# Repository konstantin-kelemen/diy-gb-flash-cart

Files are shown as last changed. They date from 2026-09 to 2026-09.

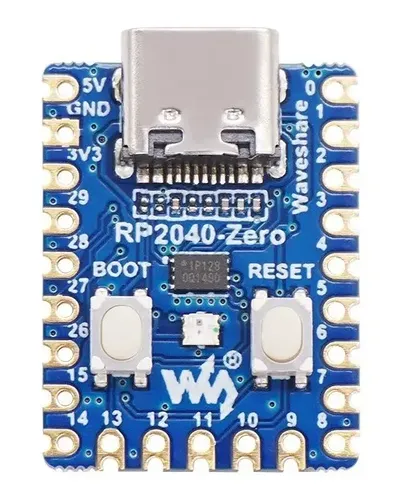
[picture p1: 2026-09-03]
references/datasheets/RP2040/RP2040-Zero.png

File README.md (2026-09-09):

# FPGA-картридж с Flash-памятью для Game Boy

Экспериментальный USB-программируемый картридж для оригинального Game Boy:
MachXO2-1200HC, NOR Flash MX29LV320E (4 МБ), F-RAM FM28V100 (128 КБ),
RP2040-Zero и преобразователи уровней SN74LVC8T245.

## С чего начать

- [Состояние проекта](docs/STATUS.md) — что реализовано и что проверено.
- [План работ](docs/ROADMAP.md) — следующие этапы и критерии готовности.
- [Документация](docs/README.md) — архитектура, испытания и приоритет источников.
- [Первый обмен USB/SPI](docs/SPI_BRINGUP.md) — подключение стенда и протокол.
- [Запись .gb во Flash](docs/PROGRAMMER.md) — чтение, запись и сравнение ROM.

## Структура репозитория

| Каталог | Содержимое |
|---|---|
| [docs/](docs/README.md) | Проектная документация и журнал испытаний |
| [hardware/](hardware/README.md) | Схемы, PCB и локальные библиотеки KiCad |
| [fpga/](fpga/README.md) | RTL, ограничения, тесты и проект Diamond |
| [firmware/](firmware/README.md) | Прошивки RP2040: SPI-тест и программатор |
| [host/](host/README.md) | Утилита записи и проверки Flash |
| [references/](references/README.md) | Техническая документация и сторонние материалы |
| [releases/](releases/README.md) | Сохранённые сборки и производственные файлы |

Электрические соединения определяет [схема картриджа](hardware/cartridge/cartridge.kicad_sch);
правила сверки приведены в [документации](docs/README.md#приоритет-источников).
Перед работой с памятью см. [режимы и требования безопасности](docs/ARCHITECTURE.md#режимы-работы).

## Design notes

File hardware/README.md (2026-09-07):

# Аппаратная часть

## Проекты

- `breakout/` — разведённая отладочная плата с производственным архивом.
- `cartridge/` — основная схема картриджа и PCB. Состояние разводки — в
  [STATUS.md](../docs/STATUS.md).

## Открытие в KiCad

Открывайте `cartridge/cartridge.kicad_pro` или `breakout/breakout.kicad_pro`.
Локальные библиотеки и 3D-модели картриджа хранятся рядом с проектом;
`fp-lib-table` использует пути относительно `${KIPRJMOD}`.
Для стандартных компонентов также нужны штатные библиотеки KiCad.

В `cartridge/sym-lib-table` пути пяти библиотек пока указывают на каталоги,
а не на конкретные `.kicad_sym`. Перед обновлением символов из библиотек
нужно исправить эти ссылки. Файлы находятся в соответствующих подкаталогах
`cartridge/libraries/`; у RP2040-Zero это `Andrews-symbols.kicad_sym`,
у остальных — файлы с датой в имени. Наличие встроенных символов в схеме
не подтверждает правильность настройки внешних библиотек.

Перед выпуском аппаратной ревизии необходимо выполнить ERC/DRC и сверить LPF с
назначением выводов символа FPGA в схеме.

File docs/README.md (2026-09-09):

# Документация

## Приоритет источников

Единственный нормативный источник электрических соединений —
`hardware/cartridge/cartridge.kicad_sch`.

При расхождении артефакты проверяются в следующем порядке:

1. схема картриджа — соединения и номиналы установленных компонентов;
2. PCB картриджа — размещение и трассировка;
3. ограничения FPGA и константы прошивки — должны соответствовать схеме;
4. сгенерированные перечни компонентов и отчёты по назначениям выводов;
5. пояснительная документация.

Таблицы подключений хранятся только в KiCad; в документации используются ссылки.

## Состав документации

- [STATUS.md](STATUS.md) — проверенные, реализованные и запланированные части.
- [ARCHITECTURE.md](ARCHITECTURE.md) — границы подсистем и требования безопасности.
- [ROADMAP.md](ROADMAP.md) — порядок первичной проверки и критерии готовности.
- [TEST_PLAN.md](TEST_PLAN.md) — обязательные проверки и сохраняемые результаты.
- [SPI_BRINGUP.md](SPI_BRINGUP.md) — подключение RP2040-Zero и протокол первого обмена.
- [PROGRAMMER.md](PROGRAMMER.md) — полный дамп, запись `.gb` и повторное чтение на Mac.
- [PROGRAMMER_PROTOCOL.md](PROGRAMMER_PROTOCOL.md) — блочный USB/SPI-протокол 3.0 и временные параметры.
- [BOM.md](BOM.md) — заметки по комплектации; не источник электрической истины.

`archive/` содержит устаревшие снимки, оставленные только для истории. Они не
должны использоваться при проектировании или закупке.

## Как поддерживать документацию

- Текущий статус хранится в `STATUS.md`, хронология испытаний — в `TEST_PLAN.md`.
- `ROADMAP.md` содержит этапы и критерии; `ARCHITECTURE.md` — общие требования.
- Подключение стенда и SPI 1.0 описаны в `SPI_BRINGUP.md`, протокол программатора 3.0 — в `PROGRAMMER_PROTOCOL.md`.
- README конфигурации содержит сборку, запуск и специфическую диагностику.
- Манифест выпуска фиксирует его исходники, инструменты, отчёты и контрольные суммы.

В остальных местах используйте ссылки вместо копирования таблиц, результатов
и протокола. Исторические манифесты и снимки исходников не актуализируются
вместе с текущим кодом.

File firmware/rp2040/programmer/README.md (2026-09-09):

# RP2040 programmer

Прошивка Waveshare RP2040-Zero для [программатора Flash](../../../docs/PROGRAMMER.md).
Бинарный USB CDC, протокол 3.0 с CRC; SPI0 Mode 0, 4 МГц. UART отключён.
Подключение — по [схеме KiCad](../../../hardware/cartridge/cartridge.kicad_sch).

## Сборка на macOS при изменении прошивки

Требуются Pico SDK с инициализированным TinyUSB, ARM GCC и CMake.
`PICO_SDK_PATH` должен указывать на каталог SDK. Из корня проекта:

```sh
cmake -S firmware/rp2040/programmer -B firmware/rp2040/programmer/build-v3 -DPICO_BOARD=waveshare_rp2040_zero
cmake --build firmware/rp2040/programmer/build-v3 -j4
```

Выход: `firmware/rp2040/programmer/build-v3/gb_cart_programmer.uf2`.
Для стендового опыта с готовым UF2 использовать общую инструкцию выше.

Проверка кода моста с моделью SPI на Mac:

```sh
python3 -m unittest discover -s firmware/rp2040/programmer/tests -v
```

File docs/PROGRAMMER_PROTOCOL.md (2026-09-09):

# Программатор: блочный протокол 3.0

[Порядок работы на Mac](PROGRAMMER.md). Версия 3 несовместима с v2;
UF2 и FPGA обновляются вместе. Размер блока — 1..1024 байта. Память адресуется
байтами, диапазон `000000..3FFFFF`. Все числа ниже, кроме длин, — hex.

## SPI

Mode 0, MSB first, 4 МГц, CS# остаётся низким весь кадр.
Интервалы до первого фронта, после последнего спада и между кадрами — ≥2 мкс.
После запуска RP2040 выдерживается 400 мс. FPGA не выдаёт стартовых команд Flash.

Запрос операции:

```text
command sequence address_hi address_mid address_lo length_hi length_lo key
[payload: length bytes, только WRITE_BLOCK]
crc_hi crc_lo
```

CRC-16/CCITT-FALSE: polynomial 1021, init FFFF, без отражения/xorout.
CRC охватывает заголовок и payload. Запрос исполняется только после снятия CS,
если длина точна, CRC верен, FPGA свободна и sequence отличается от предыдущего.
Sequence увеличивается modulo 256; после подключения сначала читается текущий.
Кадры, начатые во время busy, игнорируются целиком. Неполные и лишние кадры
не исполняются. При ошибке CRC или повторе sequence снимается ARM.

| Command | Назначение |
|---|---|
| 30 | READ_BLOCK: length=1..1024, без payload; обычное чтение разрешено без ARM |
| 31 | WRITE_BLOCK: length=1..1024, payload той же длины; требуется ARM |
| 12 | Стереть сектор по address; length=0, требуется ARM |
| 13 | Прочитать ID и вернуть Flash в read-array; length=0, требуется ARM |
| 14 | Reset/read-array F0; length=0, требуется ARM |
| 20 | ARM: address=0, length=0, key=A5 |
| 21 | LOCK: address=0, length=0, key=0 |

В остальных запросах key=0. WRITE_BLOCK буферизуется целиком до проверки CRC.
FPGA программирует байты последовательно, с Q7/Q5 polling, тайм-аутом и
проверкой прочитанного байта. FF пропускаются; утилита предварительно проверяет
полное стирание затронутых секторов. Аппаратного многобайтового программирования
самого чипа этот протокол не предполагает. На первой ошибке блок останавливается,
ARM снимается, префикс уже записанных байтов сохраняется.

### Запросы ответов

Первый принятый байт, одновременно с opcode, отбрасывается RP2040.
После opcode передаются нулевые dummy bytes:

- `01` + 8 dummy → `47 42 46 43 03 00 00 04`: GBFC, версия 3.0,
  максимальный блок 0400, little-endian.
- `02` + 10 dummy → снимок статуса с CRC:

  ```text
  50 sequence status command result_lo result_hi completed_lo completed_hi crc_hi crc_lo
  ```

- `03` + `length+2` dummy → данные последнего успешного READ_BLOCK и CRC данных.
  Допускается только после готового статуса, совпадения sequence, opcode и длины.
  Следующая операция заменяет предыдущий результат; одновременно выполняется один запрос.

Статусы: 00 success, 01 busy, 02 opcode, 03 timeout, 04 Q5 failure,
05 readback mismatch, 06 controller fault, 07 CRC, 08 address/length,
09 locked, 0A duplicate sequence. `completed` — число успешно обработанных
байтов блока до ошибки; адрес ошибки равен `address + completed`.
У ID `result_lo` — производитель C2, `result_hi` — устройство A7/A8.
LOCK не прерывает уже принятую операцию.

## Бинарный USB CDC

Кадр Mac → RP2040:

```text
47 42 33 51  length_hi length_lo  payload  crc_hi crc_lo
 G  B  3  Q
```

Ответ имеет magic `GB3R`. CRC охватывает два байта длины и payload.
USB длина — big-endian, без magic, длины и CRC. Максимальный payload запроса —
1034 байта, ответа — 1036. Байты передаются без hex-кодирования и преобразования
переводов строк; значения 00/0A/0D допустимы внутри данных.

Payload запроса: одиночный `01` (версия), `02` (статус) либо целый SPI-запрос
операции со своим CRC. Мост проверяет запрос, отправляет его один раз, опрашивает
статус и проверяет sequence/opcode/CRC. Ответ операции — 10 байт статуса;
для успешного READ_BLOCK добавляются `length` байт данных и их SPI CRC.
Все три уровня CRC проверяются утилитой Mac.

Локальная ошибка моста — payload из одного байта: E1 SPI CRC, E2 кадр/CRC/длина,
E3 busy/sequence/count, E4 timeout. Время приёма USB-кадра — до 2 с,
ожидание операции FPGA — до 7 с, чтение ответа на Mac — до 10 с.
После повреждения USB-кадра вход отбрасывается до 100 мс тишины; внутри
оставшегося payload новые magic не ищутся. При подключении Mac выдерживает 2,2 с.
Автоматические повторы отсутствуют, особенно после потенциально принятой записи.
Ошибка требует остановки и выяснения состояния стенда.

## Частота и Flash

OSCH в `programmer` — 53,20 МГц. В LPF задано 64 МГц, но Map отклоняет
это значение для OSCH и применяет 53,20 МГц. Повторный TRACE пройден
на номинальной частоте; [подробности](TEST_PLAN.md#журнал-результатов).
SPI синхронизируется двумя регистрами. RTL-тест пройден при такте FPGA
около 42,55, 53,19 и 64 МГц с SPI 4 МГц. После Map требуется подтвердить
размещение буферов в EBR, использование ресурсов, пути SPI и внешней шины.
RTL-симуляция не подтверждает задержки после размещения и качество проводного монтажа.

Общий `mx29_bus` параметризован: в programmer один шаг чтения — 4 такта,
записи — 32. При 64 МГц от OE#/CE# до выборки проходит 187,5 нс;
WE# удерживается низким 500 нс. Значения по умолчанию сохранены для
`flash_bringup` на 2,08 МГц. Таймеры programmer пересчитаны: старт 16 млн тактов,
program timeout 128 тыс., erase timeout 192 млн. При 53,20 МГц это примерно
301 мс, 2,4 мс и 3,6 с соответственно.

Алгоритм и параметры: [Macronix MX29LV320E v1.3](https://www.macronix.com/Lists/Datasheet/Attachments/8542/MX29LV320E%20T-B,%203V,%2032Mb,%20v1.3.pdf),
таблицы AC и Q7/Q5 polling на рис. 20;
[настройки OSCH MachXO2](https://www.latticesemi.com/-/media/LatticeSemi/Documents/ApplicationNotes/MO/FPGA-TN-02157-3-0-MachXO2-sysCLOCK-PLL-Design-and-User-Guide.ashx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).

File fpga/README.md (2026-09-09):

# Исходники FPGA

## Конфигурации

| Каталог target | Реализация Diamond | Ограничения / инструкция |
|---|---|---|
| `targets/internal_rom/` | `v1_0` | `constraints/internal_rom.lpf`; сборка ниже |
| `targets/flash_bringup/` | `flash_bringup` (активна по умолчанию) | Общий `internal_rom.lpf`; [инструкция](targets/flash_bringup/README.md) |
| `targets/spi_bringup/` | `spi_bringup` | `constraints/spi_bringup.lpf`; [сборка и симуляция](targets/spi_bringup/README.md) |
| `targets/game_rom/` | `game_rom` | `constraints/game_rom.lpf`; [запуск ROM из Flash](targets/game_rom/README.md) |
| `targets/game_mbc5/` | `game_mbc5` | `constraints/game_mbc5.lpf`; [LSDj и F-RAM](targets/game_mbc5/README.md) |
| `targets/programmer/` | `programmer` | `constraints/programmer.lpf`; [запись Flash](targets/programmer/README.md) |

Добавлена GAME-конфигурация MBC5 для LSDj 1 МиБ / RAM 128 КиБ.
RTL и адаптация PROGRAMMER к F-RAM проверены в симуляции; новые JEDEC
ещё не собраны. Старые выпуски PROGRAMMER с диагностикой на 82–83
несовместимы с подключённой F-RAM. Назначения — в
[схеме KiCad](../hardware/cartridge/cartridge.kicad_sch).

Каждая конфигурация содержит собственный `top` и собирается независимо.
Общие модули — в `rtl/`, тесты — в `tests/`, проект — в `diamond/`.

`examples/hello_world.v` — минимальный пример выхода FPGA,
`examples/fram_test.v` — ранний автономный тест F-RAM. Они не подключены
к проекту Diamond. Перед использованием нужны отдельная конфигурация,
проверенный LPF и испытания.

## Работа в Lattice Diamond

Открывать нужно проект `diamond/RomEmu.ldf`, сохраняя рядом всю структуру
каталога `fpga/`: пути к исходникам и ограничениям в проекте относительные.
Копировать один каталог `diamond/` в другое место не следует.

Для обычной сборки `internal_rom`:

1. Выберите в Diamond `File -> Open -> Project` и откройте
   `diamond/RomEmu.ldf`.
2. Убедитесь, что активна реализация `v1_0`. В ней должны быть подключены
   `targets/internal_rom/top.v` и `constraints/internal_rom.lpf`, а модулем
   верхнего уровня должен быть `top`.
3. В окне `Process` последовательно запустите `Synthesize Design`,
   `Map Design`, `Place & Route Design` и `Export Files -> JEDEC File`.
4. Полученный файл находится по пути
   `diamond/v1_0/RomEmu_v1_0.jed`.

Каталог `diamond/v1_0/` содержит только результаты сборки. Он исключён из Git,
может быть удалён и будет создан Diamond заново. Исходный Verilog нужно
редактировать в `targets/` и `rtl/`, ограничения — в `constraints/`, а не в
сгенерированных копиях внутри каталога реализации.

Если Diamond сообщает об отсутствующих исходниках, удалите устаревшие ссылки
из реализации и добавьте нужные файлы через `Add -> Existing File`. Параметр
`Copy source to implementation directory` при этом должен быть отключён, чтобы
в проекте не появлялись отдельные копии исходников.

### Добавление другой конфигурации

Для новой конфигурации следует создавать отдельную реализацию Diamond, не
заменяя файлы в `v1_0`. Реализацию можно добавить через
`Add -> New Implementation`, после чего подключить её `top.v`, общие модули из
`rtl/` и отдельный LPF из `constraints/`. Одновременно активна только одна
реализация; перед сборкой нужно выбрать её через `Set as Active Implementation`
и установить модуль `top` верхним уровнем.

Особенности общего LPF и предупреждения `flash_bringup` описаны в
[README конфигурации](targets/flash_bringup/README.md).

После сохранения проекта через интерфейс Diamond следует проверить, какие
файлы проекта были изменены:

```sh
git diff -- fpga/diamond/RomEmu.ldf fpga/diamond/RomEmu1.sty
git status --short
```

## Проверка назначений выводов

Перед программированием реального устройства нужно выполнить
[процедуру сверки LPF](../docs/TEST_PLAN.md#сверка-lpf). Расхождения нельзя
скрывать изменением текстовой документации.

Состояние аппаратных проверок — в [STATUS.md](../docs/STATUS.md),
сохранённые сборки — в [releases/](../releases/README.md).

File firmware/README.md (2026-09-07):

# Прошивка RP2040

Конфигурация [rp2040/spi_bringup](rp2040/spi_bringup/README.md):
USB CDC-консоль и SPI0 для запроса версии FPGA и повторных тестов.
Команд памяти в ней нет.

[rp2040/programmer](rp2040/programmer/README.md) — USB/SPI-мост для записи Flash,
работающий с FPGA `programmer` и `host/gbflash.py`.
[Полная инструкция](../docs/PROGRAMMER.md),
[аппаратный результат](../docs/TEST_PLAN.md#журнал-результатов).

Инструкции сборки находятся в README соответствующей конфигурации.
[Подключение стенда](../docs/SPI_BRINGUP.md) общее для обеих конфигураций;
[протокол программатора](../docs/PROGRAMMER_PROTOCOL.md) описан отдельно.

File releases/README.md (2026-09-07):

# Выпуски

В этом каталоге хранятся сохранённые выходные файлы. Уровень проверки каждого
артефакта указан отдельно: здесь есть успешные и неуспешные FPGA-сборки,
а также UF2 без подтверждённого аппаратного испытания.

Каждый новый выпуск должен содержать манифест с именем конфигурации, исходным
коммитом, версией инструментов, контрольными суммами и результатами проверки
(для FPGA — также сводкой DRC и временного анализа). Если сборка сделана
с незакоммиченными изменениями, нужен точный снимок исходников с суммами:
одного базового коммита недостаточно.
Артефакт сборки нельзя считать проверенным на аппаратуре, если такая проверка
явно не зафиксирована в манифесте.

## FPGA

- [spi_bringup](fpga/spi_bringup/MANIFEST.md) — оригинальный рабочий SPI-тест,
  протокол 1.0, аппаратный PASS 1000/1000.
- [programmer-v3](fpga/programmer-v3/MANIFEST.md) — рабочий блочный программатор,
  аппаратный PASS полного цикла Flash; сохранены JEDEC и успешный TRACE.
- [flash-bringup-pass](fpga/flash-bringup-pass/MANIFEST.md) — рабочая сборка
  Flash-теста со стартовым сбросом; PASS после прошивки и выключения/включения питания.
- [flash-bringup-fail](fpga/flash-bringup-fail/MANIFEST.md) — прежняя сборка с FAIL.
- [internal-rom-baseline](fpga/internal-rom-baseline/MANIFEST.md) — базовая
  проверенная конфигурация с внутренним ПЗУ.

## RP2040

[spi_bringup/gb_cart_rp2040.uf2](rp2040/spi_bringup/gb_cart_rp2040.uf2) —
последняя локальная сборка для USB/SPI. [Манифест](rp2040/spi_bringup/MANIFEST.md)
содержит метаданные, SHA-256 и аппаратный результат: 1000/1000, PASS,
включая успешный повтор после выключения/включения питания. [Сборка из исходников](../firmware/rp2040/spi_bringup/README.md#сборка).

[programmer-v3](rp2040/programmer-v3/MANIFEST.md) — блочный программатор,
актуальный UF2 для протокола 3.0. Полный цикл Flash проверен с
[FPGA programmer-v3](fpga/programmer-v3/MANIFEST.md) — PASS.
Исторический снимок FPGA в выпуске UF2 предшествует исправлению timing. [programmer v2](rp2040/programmer/MANIFEST.md) —
прежний несовместимый выпуск.

## Отладочная плата

[breakout/v1.0.zip](breakout/v1.0.zip) — производственный архив отладочной платы;
отдельный манифест выпуска ещё не подготовлен.

## Проверка контрольных сумм

Из корня репозитория:

```sh
cd releases/fpga/flash-bringup-pass
shasum -a 256 -c SHA256SUMS.txt
```

В `.gitattributes` для всего `releases/`, включая снимки исходников и
манифесты, отключено преобразование переводов строк. Файлы сохраняются
побайтово независимо от `core.autocrlf`.

В семи текстовых файлах `flash-bringup-pass` и отчёте `.pad` выпуска
`flash-bringup-fail` восстановлены исходные CRLF, подтверждённые опубликованными
SHA-256. Список сумм и манифесты сохранены без изменений. Проверены все суммы
из `SHA256SUMS.txt` и таблиц двух остальных FPGA-манифестов; расхождений нет.

Манифесты описывают состояние на момент выпуска. Их упоминания рабочего дерева
и следующих шагов относятся к тому испытанию; актуальный план — в
[документации проекта](../docs/README.md).

При подготовке нового выпуска сначала завершите его содержимое и манифест,
затем вычислите контрольные суммы. После добавления файлов в Git проверьте
суммы повторно на чистом checkout.

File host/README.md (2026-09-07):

# Программа для компьютера

`gbflash.py` — утилита macOS для работы с Flash через USB CDC прошивки RP2040
`programmer`. [Подготовка и полный цикл чтения, записи и сравнения](../docs/PROGRAMMER.md).

Проверка утилиты из корня проекта:

```sh
python3 -m unittest discover -s host/tests -v
```

Дополнительные команды доступны через `python3 host/gbflash.py --help`.

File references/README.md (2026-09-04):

# Справочные материалы

- `datasheets/` содержит локальные копии технической документации на выбранные
  компоненты.
- `third-party/` содержит сторонние аппаратные проекты и модели корпусов.

Сторонние файлы не являются частью собственного проекта. Для каждого
импортированного материала следует сохранять исходную лицензию и сведения о
происхождении рядом с файлами.

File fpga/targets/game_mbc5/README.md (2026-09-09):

# LSDj: MBC5 и F-RAM

Отдельная GAME-конфигурация для `roms/lsdj9_4_2.gb`: 1 МиБ ROM,
заголовок `1B 05 04`, 128 КиБ RAM. RTL проверен; сборка Diamond,
post-route timing и запуск на Game Boy ещё не выполнены.
Соединения хранятся в [схеме KiCad](../../../hardware/cartridge/cartridge.kicad_sch).

## Поведение

Регистры соответствуют [MBC5 / Pan Docs](https://raw.githubusercontent.com/gbdev/pandocs/master/src/MBC5.md):
фиксированный банк 0 в `0000–3FFF`, переключаемый банк в `4000–7FFF`,
RAM в `A000–BFFF` при активном CS#. Банк ROM 0 допустим в обоих окнах.
Запись в `2000–2FFF` задаёт младшие 8 бит, в `3000–3FFF` — девятый бит.
Физически используются только младшие 6 бит: образ 1 МиБ зеркалируется.

Запись в `0000–1FFF` разрешает RAM, если младшая тетрада равна A;
остальные значения запрещают RAM. В `4000–5FFF` выбирается один из
16 банков RAM младшей тетрадой данных. Rumble отсутствует.
После конфигурации и при RESET# LOW: банк ROM 1, RAM 0, RAM запрещена.
Регистры принимают данные на положительном фронте WR# при RD# HIGH.
Неиспользуемые записи игнорируются. Чтение запрещённой RAM возвращает FF.

Flash WE# постоянно HIGH. Памяти выбираются взаимоисключающе, FPGA
выдаёт данные на общую шину только при записи RAM. Вход преобразователя
Game Boy остаётся включённым между транзакциями и после WR#, чтобы не
обрезать удержание данных при записи регистров. При чтении направление
меняется к Game Boy; при сбросе преобразователь отключён.

F-RAM CE# активен только на время обращения RD#/WR# и отпускается между
ними. Это обеспечивает отдельный цикл precharge, если длительность паузы
соответствует [FM28V100, стр. 8–11](https://www.infineon.com/assets/row/public/documents/10/49/infineon-fm28v100-1-mbit-128k-x-8-f-ram-memory-datasheet-en.pdf).
Для 3,3 В требуются CE# LOW не менее 60 нс, precharge не менее 30 нс,
WE# LOW не менее 18 нс, setup данных записи не менее 15 нс.
RTL не растягивает внешние импульсы и не содержит внутреннего генератора.

## Проверка на Mac

Из корня проекта с установленным Icarus Verilog:

```sh
iverilog -g2012 -Wall -s game_mbc5_tb -o /tmp/game-mbc5.vvp fpga/targets/game_mbc5/top.v fpga/tests/game_mbc5_tb.sv
vvp /tmp/game-mbc5.vvp
python3 -m unittest discover -s host/tests -v
```

Покрытие и результаты — в [журнале испытаний](../../../docs/TEST_PLAN.md#журнал-результатов).
Модель: Flash 70 нс, F-RAM 90 нс, преобразователь 5 нс; чтение проверяется
через 160 нс. Проверяются длительности CE#/WE#, precharge и setup данных.
Host-тест выполняет два полных чтения 4 МиБ и запись LSDj между ними
для Top/Bottom Boot; при отсутствии локального ROM используется синтетический
образ того же размера. Это симуляция, аппаратные дампы не создаются.

## Сборка в Windows

Открыть `fpga/diamond/RomEmu.ldf`, выбрать **game_mbc5**, верхний модуль `top`.
Выполнить синтез, Map, Place & Route, TRACE и экспорт JEDEC.
Ожидаемый путь — `fpga/diamond/game_mbc5/RomEmu_game_mbc5.jed`.
Для записи Flash отдельно собрать обновлённый **programmer**;
RP2040 `programmer-v3` и текущая утилита Mac совместимы без изменения протокола.
Старый JEDEC `releases/fpga/programmer-v3/` не подходит для подключённой F-RAM.

LPF фиксирует выводы и электрические стандарты. Временные требования пока
не закрыты; отсутствие ошибок TRACE без заданных внешних требований
не является PASS. Проверить `.pad` по [процедуре](../../../docs/TEST_PLAN.md#сверка-lpf).
Проверить задержки адреса к памяти, RD#/WR#/CS# к CE#/OE#/WE#, памяти
к Game Boy, Game Boy к F-RAM и setup/hold регистров относительно WR#.
Учесть преобразователи, разводку, выключение выходов памяти и смену DIR,
hold данных относительно конца WE#/CE#, reset recovery/removal и старт F-RAM.
Поддержка ускоренного режима GBC аппаратно не подтверждена.

[Состав выпуска](../../../releases/README.md),
[порядок аппаратных испытаний](../../../docs/ROADMAP.md).

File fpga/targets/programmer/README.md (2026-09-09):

# FPGA programmer

Отдельная конфигурация PROGRAMMER без интерфейса Game Boy.
`top.v` объединяет `programmer_block.v`, `mx29_programmer.v` и `mx29_bus.v`.
Входной и выходной блоки по 1 КиБ хранятся в синхронной памяти для вывода в EBR.
LPF: `constraints/programmer.lpf`. Диагностические выходы удалены;
CE#/OE#/WE# F-RAM постоянно HIGH. Протокол v3 и прошивка RP2040 не изменены.

Старый выпуск для стенда без F-RAM: [JEDEC, отчёты и манифест](../../../releases/fpga/programmer-v3/MANIFEST.md).
[Прошивка и стенд](../../../docs/PROGRAMMER.md),
[протокол и временные параметры](../../../docs/PROGRAMMER_PROTOCOL.md).
Новая адаптация ещё не собрана в Diamond. Путь результата: `fpga/diamond/programmer/RomEmu_programmer.jed`.
Ограничения timing — в [описании протокола](../../../docs/PROGRAMMER_PROTOCOL.md#частота-и-flash).

## Сборка в Diamond

При изменении исходников в Windows открыть `fpga/diamond/RomEmu.ldf`,
выбрать **programmer**, выполнить синтез, Map, Place & Route, TRACE
и экспорт JEDEC. Проверить ресурсы, timing и выводы по
[плану испытаний](../../../docs/TEST_PLAN.md).

## RTL-проверка

Из корня проекта на Mac с Icarus Verilog:

```sh
iverilog -g2012 -s programmer_block_tb -o /tmp/programmer-block.vvp fpga/rtl/mx29_bus.v fpga/rtl/mx29_programmer.v fpga/rtl/programmer_block.v fpga/tests/programmer_block_tb.sv
vvp /tmp/programmer-block.vvp
```

Проверены SPI 4 МГц, блоки, CRC, границы, ID/стирание/запись, LOCK,
повреждённые/неполные/лишние кадры, дублирование sequence, кадр во время busy,
Q5 и тайм-аут. Модель задерживает данные Flash на 70 нс и контролирует
момент чтения и длительность WE#. Это не post-route и не аппаратная проверка.
`programmer_spi.v` и `programmer_tb.sv` оставлены для регрессии прежнего v2;
актуальная FPGA-конфигурация их не использует.

Проверка отключения F-RAM на верхнем уровне:

```sh
iverilog -g2012 -s programmer_top_tb -o /tmp/programmer-top.vvp fpga/targets/programmer/top.v fpga/rtl/mx29_bus.v fpga/rtl/mx29_programmer.v fpga/rtl/programmer_block.v fpga/tests/programmer_top_tb.sv
vvp /tmp/programmer-top.vvp
```

Примитивы генератора и стартового сброса заменены функциональными моделями.

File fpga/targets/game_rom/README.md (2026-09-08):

# Game Boy: ROM 32 КиБ из Flash

`game_rom` выдаёт первые 32 КиБ MX29LV320E в адресах Game Boy `0000–7FFF`.
Поддерживается ROM ONLY без RAM и маппера: заголовок `0147–0149 = 00 00 00`
([формат заголовка](https://gbdev.io/pandocs/The_Cartridge_Header.html)).
У записанного `flash-test-20260907-232422/rom.gb` этот формат подтверждён.

## Реализация

Асинхронный путь: `gb_a[14:0] → flash_a[14:0]`, `flash_d → gb_d`.
Старшие семь бит адреса Flash равны нулю. Сохранена байтовая адресация
программатора: `flash_a[0]` подключён к A−1 (DQ15), BYTE# — LOW.
Назначения выводов Game Boy и направление `data_dir = 1` перенесены
из проверенной конфигурации `internal_rom`, выводы Flash — из `programmer`.

Flash CE#/OE# и преобразователь данных включаются только при `A15 = 0`
и `RD# = 0`. В остальных случаях шина данных Game Boy освобождена.
WE# Flash постоянно HIGH; FPGA не управляет входной шиной `flash_d`.
Записи Game Boy игнорируются. CS# не используется: здесь нет внешней RAM.

Это отдельный режим GAME: SPI, маппер, F-RAM и переключение в PROGRAMMER
в этой конфигурации не реализованы. Для новой записи ROM используется
[программатор](../../../docs/PROGRAMMER.md), затем снова загружается `game_rom`.
Flash должна находиться в режиме чтения массива; программатор возвращает её
в этот режим после операций. Содержимое Flash при прошивке FPGA не меняется.

## Сборка и запуск

1. В Windows открыть `fpga/diamond/RomEmu.ldf`, выбрать **game_rom** через
   `Set as Active Implementation`. Верхний модуль — `top`.
2. Выполнить `Synthesize Design`, `Map Design`, `Place & Route Design`,
   анализ TRACE и `Export Files → JEDEC File`.
3. Сверить `.pad` с `fpga/constraints/game_rom.lpf` по
   [процедуре LPF](../../../docs/TEST_PLAN.md#сверка-lpf).
4. При отключённом Game Boy прошить
   `fpga/diamond/game_rom/RomEmu_game_rom.jed` через Diamond Programmer.
5. Подключить стенд к Game Boy с согласованным питанием по
   [архитектуре](../../../docs/ARCHITECTURE.md#питание), отключив USB RP2040.
   Включить Game Boy. Ожидается запуск записанного ROM после заставки.

Ранее выполненное сравнение `after.bin` с `rom.gb` подтверждает содержимое
Flash; повторно записывать тот же ROM для этого запуска не требуется.
Критерий аппаратной проверки — характерный экран и работа записанной программы,
а не только логотип Nintendo. Результат сохраняется в
[журнале](../../../docs/TEST_PLAN.md#журнал-результатов).

## Временные параметры

В схеме нет тактового генератора и синхронного контроллера Flash.
В LPF намеренно нет FREQUENCY и BLOCK ASYNCPATHS. Отсутствие setup/hold ошибок
само по себе не подтверждает скорость асинхронного тракта.
После размещения проверить задержки `gb_a → flash_a`,
`gb_a[15]/gb_rd_n → CE#/OE#/data_oe_n` и `flash_d → gb_d`.
Полный бюджет чтения включает преобразователи уровней, FPGA, время доступа
Flash и разводку стенда; его нужно сопоставить с моментом выборки Game Boy.

RTL-тест использует задержки Flash 70 нс и преобразователя данных 10 нс,
проверяет данные через 100 нс после изменения входов. Это параметры модели,
а не измерение стенда или результат post-route анализа. Аппаратная проверка
пройдена: игра загружается и работает стабильно — **PASS**
([журнал](../../../docs/TEST_PLAN.md#журнал-результатов)). [Сборка и отчёты](../../../releases/fpga/game_rom/).

## RTL-проверка на Mac

Из корня проекта с установленным Icarus Verilog:

```sh
iverilog -g2012 -Wall -s game_rom_tb -o /tmp/game-rom.vvp fpga/targets/game_rom/top.v fpga/tests/game_rom_tb.sv
vvp /tmp/game-rom.vvp
```

Тест перебирает весь ROM, всё пространство вне ROM, случайные адреса,
изменение адреса при удержании RD#, отдельные импульсы RD# и записи CPU.
Ожидается `PASS game_rom`.

Для проверки с конкретным ROM вместо случайных данных:

```sh
python3 - /полный/путь/к/rom.gb /tmp/game-rom.hex <<'PY'
from pathlib import Path
import sys
rom = Path(sys.argv[1]).read_bytes()
if len(rom) != 32768 or rom[0x147:0x14a] != bytes(3):
    sys.exit("Ожидается ROM ONLY 32 КиБ без RAM")
Path(sys.argv[2]).write_text("".join(f"{b:02x}\n" for b in rom))
PY
vvp /tmp/game-rom.vvp +ROM=/tmp/game-rom.hex
```

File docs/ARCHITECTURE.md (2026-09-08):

# Архитектура

Документ описывает целевое устройство и требования к интеграции. Степень их
реализации и результаты проверок указаны в [STATUS.md](STATUS.md).

## Общая схема

```text
Game Boy, шина 5 В
        |
        v
Преобразователи уровней SN74LVC8T245
        |
        v
FPGA MachXO2 <---- SPI ----> RP2040-Zero <---- USB ----> программа на компьютере
     |       |
     v       v
4 МБ Flash  128 КБ F-RAM
```

FPGA — единственное устройство, непосредственно управляющее параллельными
шинами Flash и F-RAM. RP2040 передаёт FPGA команды и данные по SPI и не имеет
отдельного подключения к полной параллельной шине памяти.

Для MBC5 предусмотрена общая адресная шина и шина данных Flash/F-RAM
с раздельными CE#/OE#/WE#. Назначения и состояния — в
[схеме подключения](../hardware/cartridge/cartridge.kicad_sch). Одновременно выдавать данные
на общую шину может только одна память либо FPGA при записи.

## Режимы работы

### GAME

Транзакции инициирует Game Boy. Flash доступна только для чтения, а её `WE#`
остаётся неактивным независимо от команд интерфейса программатора.

### PROGRAMMER

Сторона Game Boy не может инициировать транзакции памяти. Контроллер Flash в
FPGA получает право на чтение, стирание и запись только после явного выбора
этого режима.

После записи весь записанный диапазон должен быть прочитан обратно по пути
`Flash → FPGA → RP2040 → USB → компьютер` и побайтово сравнён с исходным файлом.
При несовпадении указываются адрес, ожидаемый и фактический байт. До успешной
проверки запуск записанного образа на Game Boy запрещён.

Два владельца не должны одновременно управлять шиной памяти. Безопасные
неактивные состояния должны сохраняться также во время конфигурации FPGA и
переходных процессов любого источника питания.

## Ответственность подсистем

- MX29LV320E хранит ПЗУ Game Boy и работает в режиме x8.
- FM28V100 хранит сохранения без батареи.
- FPGA выполняет декодирование адреса, переключение банков, формирование
  временных параметров шины памяти и арбитраж.
- Прошивка RP2040 реализует передачу данных по USB и SPI-команд.
- Программа на компьютере полностью читает данные обратно, сравнивает их и
  сообщает адрес первого несовпадения.

## Питание

Game Boy предоставляет 5 В, а FPGA и память работают от 3,3 В. USB и Game Boy
не должны подавать питание друг в друга. Финальная схема стабилизатора,
изоляция источников и поведение при одновременном подключении пока не приняты.

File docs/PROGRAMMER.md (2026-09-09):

# Чтение и запись Flash с Mac

Стенд: Mac → USB → RP2040-Zero → SPI → FPGA → MX29LV320E, 4 МиБ
(4 194 304 байта), режим x8. Для FPGA и RP2040 используется `programmer`,
блочный протокол 3.0. Game Boy отключён. [Подключение и питание](SPI_BRINGUP.md).
[Текущее состояние проверок](STATUS.md), [этапы и критерии](ROADMAP.md).

## Подготовка FPGA в Windows

Для монтажа с F-RAM собрать обновлённый **programmer** по
[инструкции](../fpga/targets/programmer/README.md#сборка-в-diamond), проверить
назначения и timing, сохранить выпуск и прошить полученный JEDEC.
Новая сборка ещё не выполнена. [Старый JEDEC и манифест](../releases/fpga/programmer-v3/MANIFEST.md)
сохраняются для прежнего стенда без F-RAM.

## Подготовка Mac

Все команды ниже выполнять из корня проекта в одном окне Terminal.

```sh
python3 -m venv .venv
source .venv/bin/activate
python -m pip install pyserial
```

Загрузить готовую прошивку RP2040: удерживая BOOTSEL, подключить плату к Mac
по USB. После появления диска `RPI-RP2` выполнить:

```sh
cp releases/rp2040/programmer-v3/gb_cart_programmer.uf2 /Volumes/RPI-RP2/
```

Плата перезапустится, диск исчезнет, появится USB CDC-порт.
[Манифест UF2](../releases/rp2040/programmer-v3/MANIFEST.md).
Включить питание FPGA. Найти порт:

```sh
ls /dev/cu.usbmodem*
```

```sh
FLASH_PORT=/dev/cu.usbmodem1234561
python host/gbflash.py --port "$FLASH_PORT" info
```

Ожидается `MX29LV320E: C2 A8, Bottom Boot, PROGRAMMER` либо
`MX29LV320E: C2 A7, Top Boot, PROGRAMMER`. Команда `info` читает ID и
возвращает Flash в режим чтения; содержимое памяти не меняется.
При ошибке не переходить к следующим шагам.

Создать отдельный каталог для этого испытания:

```sh
FLASH_RUN="$PWD/flash-test-$(date +%Y%m%d-%H%M%S)"
mkdir "$FLASH_RUN"
```

Обновлённый FPGA PROGRAMMER совместим с RP2040 `programmer-v3` и текущей
утилитой Mac; блочный протокол остаётся 3.0.
Прежний релиз `programmer` использует v2 и с обновлённой утилитой несовместим.
[Описание протокола и временных параметров](PROGRAMMER_PROTOCOL.md).

## 1. Считать все 4 МиБ в файл

```sh
/usr/bin/time -p python host/gbflash.py --port "$FLASH_PORT" read "$FLASH_RUN/before.bin" --address 0 --length 0x400000
```

Дождаться `Read: 4194304 bytes` без ошибок. Проверить размер и сохранить SHA-256:

```sh
python -c 'import pathlib, sys; p = pathlib.Path(sys.argv[1]); n = p.stat().st_size; print(f"{p.name}: {n} bytes"); sys.exit(0 if n == 4194304 else 1)' "$FLASH_RUN/before.bin"
shasum -a 256 "$FLASH_RUN/before.bin" > "$FLASH_RUN/before.sha256"
```

`before.bin` — исходное содержимое всего чипа перед записью.
`read` не перезаписывает существующий файл. При ошибке остаётся неполный дамп;
такой файл не считается успешным результатом. Для повторного запуска создать
новый каталог испытания.

## 2. Записать файл .gb

Указать путь к нужному ROM. Принимаются непустые файлы до 4 МиБ
включительно — по ёмкости Flash. Ниже LSDj приведён как пример.
Сохранить его копию в каталоге испытания, чтобы последующее сравнение выполнялось
с теми же байтами:

```sh
FLASH_ROM="$PWD/roms/lsdj9_4_2.gb"
cp "$FLASH_ROM" "$FLASH_RUN/rom.gb"
```

После успешного полного чтения на шаге 1 выполнить запись с адреса 0.
Размер файла проверяется утилитой до обращения к устройству:

```sh
/usr/bin/time -p python host/gbflash.py --port "$FLASH_PORT" write "$FLASH_RUN/rom.gb" --erase
```

`--erase` стирает целиком секторы, пересекающие ROM, включая остаток последнего
сектора за концом файла. Другие секторы не меняются. Утилитой проверяется
стирание, записывается образ, затем выполняется встроенное чтение и сравнение.
Дождаться `Result: SUCCESS`. При ошибке остановить испытание.
Встроенная проверка не создаёт файл дампа; он сохраняется отдельным шагом ниже.

## 3. Считать все 4 МиБ повторно и сравнить с ROM

```sh
/usr/bin/time -p python host/gbflash.py --port "$FLASH_PORT" read "$FLASH_RUN/after.bin" --address 0 --length 0x400000
```

Дождаться `Read: 4194304 bytes` без ошибок. Проверить полный размер дампа и
побайтово сравнить диапазон от адреса 0 до конца ROM с сохранённым `.gb`:

```sh
python - "$FLASH_RUN/rom.gb" "$FLASH_RUN/after.bin" <<'PYCOMPARE'
from pathlib import Path
import sys
rom = Path(sys.argv[1]).read_bytes()
dump = Path(sys.argv[2]).read_bytes()
if not 0 < len(rom) <= 4194304:
    sys.exit("FAIL: размер ROM должен быть не больше 4 МиБ")
if len(dump) != 4194304:
    sys.exit(f"FAIL: размер дампа {len(dump)}, ожидалось 4194304")
for address, expected in enumerate(rom):
    actual = dump[address]
    if actual != expected:
        sys.exit(f"FAIL: адрес 0x{address:06X}, ROM={expected:02X}, Flash={actual:02X}")
print(f"PASS: побайтово проверено {len(rom)} байт ROM; полный дамп — {len(dump)} байт")
PYCOMPARE
shasum -a 256 "$FLASH_RUN/rom.gb" "$FLASH_RUN/after.bin" > "$FLASH_RUN/after.sha256"
```

Зафиксировать результат и контрольные суммы загруженных UF2/JEDEC в
[журнале испытаний](TEST_PLAN.md#журнал-результатов).

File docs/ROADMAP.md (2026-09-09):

# План работ над FPGA-картриджем с Flash-памятью для Game Boy

**Обновлено:** 2026-09-09

**Назначение:** последовательная первичная проверка с измеримыми критериями
готовности

## Цель ближайшего цикла

Запустить `roms/lsdj9_4_2.gb` с MBC5: ROM 1 МиБ, F-RAM 128 КиБ.
Используются отдельные сборки GAME и PROGRAMMER. Следующая работа — этапы 13–16.

[Текущее состояние](STATUS.md), [процедуры и журнал испытаний](TEST_PLAN.md),
[чтение и запись Flash на Mac](PROGRAMMER.md).

## Последовательность работ

### Этап 0. Сохранить рабочую базовую конфигурацию — выполнено

Рабочая база сохранена в [выпуске](../releases/fpga/internal-rom-baseline/MANIFEST.md).

**Критерий:** конфигурация воспроизводится из сохранённых исходников и артефактов.

### Этап 1. Проверить подключение MX29LV320E

**Критерий:** монтаж соответствует схеме, подтверждены питание и режим x8;
CE#/OE#/WE# неактивны при включении и конфигурации FPGA.
[Процедуры проверки](TEST_PLAN.md#проверка-аппаратной-части).

### Этап 2. Проверить цикл чтения Flash

Чтение реализовано в `fpga/rtl/mx29_bus.v`.

**Критерий:** данные стабильны, временные параметры Flash соблюдены,
конфликтов на шине нет.

### Этап 3. Проверить тракт FPGA ↔ Flash

**Критерий:** ID и чтение выбранных адресов повторяемы; после чтения ID
Flash возвращается в режим чтения массива.

### Этап 4. Подготовить контроллер стирания и записи Flash

Контроллер реализован и аппаратно проверен в программаторе v3.

**Критерий:** чтение, стирание, запись, опрос готовности, тайм-аут и возврат
в режим чтения проходят проверку. [Протокол](PROGRAMMER_PROTOCOL.md).

### Этап 5. Зафиксировать безопасное владение шиной

PROGRAMMER используется при отключённом Game Boy.

**Критерий:** одновременное управление памятью двумя владельцами невозможно.
Интегрированный арбитраж относится к последующему циклу.

### Этап 6. Запустить SPI между RP2040 и FPGA

**Проверено — PASS:** SPI bring-up и блочный обмен v3.

**Критерий:** повторные запросы завершаются без ошибок передачи.

### Этап 7. Сохранить полный дамп Flash — выполнено

**Проверено — PASS:** полный дамп Flash сохранён.

**Критерий:** файл содержит 4 194 304 байта, ошибок чтения нет.

### Этап 8. Записать файл .gb — выполнено

**Проверено — PASS:** записан ROM 32 КиБ.

**Критерий:** затронутые секторы стёрты, запись и встроенная проверка успешны.

### Этап 9. Сохранить повторный дамп и сравнить с ROM — выполнено

**Проверено — PASS:** повторный полный дамп совпал с ROM в записанном диапазоне.

**Критерий:** размер дампа — 4 194 304 байта; совпадают все байты ROM.

### Этап 10. Запустить Game Boy из внешней Flash — выполнено

**Проверено — PASS:** игра ROM ONLY 32 КиБ загружается и работает стабильно.

**Критерий:** запускается и работает программа, записанная во Flash.
[Конфигурация](../fpga/targets/game_rom/README.md).

### Этап 11. Подготовить подключение MBC5 и F-RAM — выполнено

**Проверено — PASS:** схема MBC5/F-RAM и назначения LPF согласованы.

**Критерий:** соединения и пассивные компоненты заданы в KiCad; конфликтов выводов нет.

### Этап 12. Реализовать MBC5 и доступ к F-RAM — RTL выполнен

**RTL — PASS:** 64 банка ROM и 16 банков RAM, сброс, запрет RAM,
границы окон и направление данных. PROGRAMMER удерживает F-RAM отключённой.

**Критерий:** выбор банков и чтение/запись корректны; записи маппера
не меняют память, запрещённая RAM не изменяется, Flash WE# постоянно HIGH.
[Реализация](../fpga/targets/game_mbc5/README.md).

### Этап 13. Подготовить сборку Diamond

Собрать GAME с MBC5, совместимый программатор и конфигурацию проверки F-RAM. Сверить `.pad`
со схемой и LPF. Проверить post-route задержки чтения ROM, записи регистров,
чтения/записи F-RAM и смены направления с учётом внешних микросхем.

**Критерий успеха:** соединения разведены, проверки сборки и временные
требования выполнены. В `releases/` сохранены артефакты, отчёты, манифест,
контрольные суммы и совместимость FPGA/RP2040/утилиты Mac; для сборки
с незакоммиченными изменениями — точный снимок исходников.

### Этап 14. Подключить и проверить F-RAM

Выполнить монтаж по схеме этапа 11 и аппаратную проверку чтения/записи
128 КиБ F-RAM. Процедуру и фактический результат хранить в
[TEST_PLAN.md](TEST_PLAN.md).

**Критерий успеха:** проверены все адреса F-RAM, шаблоны данных и отсутствие
наложения банков; чтение совпадает с записью, при неактивном WE# данные
не изменяются.

### Этап 15. Записать и проверить ROM LSDj

Выполнить два полных дампа Flash с записью LSDj между ними и побайтовым
сравнением записанного диапазона второго дампа с исходным ROM на Mac.

**Критерий успеха:** оба дампа имеют размер 4 194 304 байта; все 1 048 576 байт
ROM совпадают со вторым дампом, время операций измерено. Встроенная проверка
записи дополняет сравнение файлов.

### Этап 16. Проверить LSDj на Game Boy

Прошить GAME с MBC5, запустить LSDj, создать короткую композицию,
проверить воспроизведение, сохранить и загрузить её средствами LSDj.

**Критерий успеха:** LSDj стабильно запускается, управление и воспроизведение
работают; сохранённая композиция загружается с совпадающими данными.

## Последующий цикл

После аппаратной проверки LSDj объединить GAME с MBC5 и PROGRAMMER в одной
FPGA-сборке: определить выбор режима, реализовать исключительное владение
Flash, проверить переходы в симуляции и Diamond. Аппаратный критерий —
полный цикл записи с двумя дампами и запуск LSDj без перепрошивки FPGA.

## За пределами ближайшего цикла

- Другие мапперы.
- Передача сохранений по USB.
- Автоматическое переключение владельцев Flash во время работы программы.
- Финальная PCB и корпус.

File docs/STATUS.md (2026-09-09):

# Состояние проекта

**Актуализировано по репозиторию:** 2026-09-09. Аппаратные результаты приведены
по сохранённому [журналу испытаний](TEST_PLAN.md#журнал-результатов).

| Подсистема | Состояние | Подробности |
|---|---|---|
| Прошивка MachXO2, внутреннее ПЗУ, автономный Flash-тест, SPI bring-up | Результаты ранних этапов сохранены | [Журнал](TEST_PLAN.md#журнал-результатов) |
| Программатор Flash v3 | Аппаратный PASS: два дампа 4 МиБ и запись ROM 32 КиБ; TRACE пройден на 53,2 МГц | [Выпуск](../releases/fpga/programmer-v3/MANIFEST.md), [инструкция](PROGRAMMER.md) |
| GAME ROM ONLY 32 КиБ | Игра из Flash работает стабильно — аппаратный PASS | [Конфигурация](../fpga/targets/game_rom/README.md) |
| MBC5 / F-RAM | RTL PASS: ROM 1 МиБ, RAM 128 КиБ; PROGRAMMER отключает F-RAM. Новые сборки Diamond и аппаратная проверка не выполнены | [Конфигурация](../fpga/targets/game_mbc5/README.md) |
| Отладочная PCB | Разведена, производственный архив сохранён; манифест не подготовлен | [Выпуски](../releases/README.md) |
| Основная PCB | Схема подготовлена; разводка не завершена | [Аппаратная часть](../hardware/README.md) |

## Пока не реализовано

- Интегрированный арбитраж `GAME / PROGRAMMER`.
- Передача сохранений по USB; другие мапперы кроме MBC5.
- Автоматическая сверка схемы и LPF, непрерывная интеграция.

## Ближайшая работа

F-RAM пока не подключена. Следующие шаги:

1. Собрать GAME MBC5 и PROGRAMMER в Diamond, проверить назначения и timing.
2. Подготовить аппаратный тест F-RAM, выполнить монтаж и проверить 128 КиБ.
3. Записать LSDj с двумя полными дампами Flash, проверить запуск и сохранения.

Критерии — в [ROADMAP.md](ROADMAP.md). Объединение GAME / PROGRAMMER
отложено до аппаратной проверки LSDj.

Остаются проектирование питания, ERC/DRC и разводка основной платы;
для FPGA — внешние временные требования и запас на разброс частоты OSCH.

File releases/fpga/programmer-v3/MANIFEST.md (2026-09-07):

# FPGA programmer-v3 — проверенный выпуск 2026-09-07

Проверен полный цикл Flash: два дампа по 4 МиБ, стирание сектора,
запись ROM 32 КиБ и побайтовое сравнение — **PASS**.
Подробности испытания — в [журнале](../../../docs/TEST_PLAN.md#журнал-результатов).

## Сборка и совместимость

- FPGA: `LCMXO2-1200HC-4TG100C`, верхний модуль `top`.
- Конфигурация Diamond: `programmer`.
- Инструменты: Lattice Diamond 3.14.0.75.2.
- Время Bitgen по отчёту: 2026-09-07 23:10:05; часовой пояс не указан.
- Точный исходный коммит сборки в отчётах не зафиксирован.

Совместим с [RP2040 programmer-v3](../../rp2040/programmer-v3/MANIFEST.md)
и [host/gbflash.py](../../../host/gbflash.py), протокол 3.0,
блоки до 1 КиБ, SPI 4 МГц. Выпуски v2 несовместимы.
Снимок FPGA-исходников в старом выпуске RP2040 v3 предшествует исправлению
timing; для прошивки используется JEDEC из этого каталога.

## Результаты Diamond

- Map: 506/640 SLICE, 2/7 EBR, 0 ошибок, 1 предупреждение.
- TRACE: 0 setup / 0 hold ошибок при constraint 53,200001 МГц;
  минимальный setup slack +1,614 нс, hold +0,287 нс.
- Map отклонил FREQUENCY 64 МГц для OSCH и применил NOM_FREQ 53,20 МГц.
  Проверка timing до 64 МГц этим отчётом не подтверждена.
- Place & Route: все соединения разведены, 0 ошибок.
- Bitgen DRC: 0 ошибок, 0 предупреждений.

## Файлы

| Файл | Назначение |
| --- | --- |
| [RomEmu_programmer.jed](RomEmu_programmer.jed) | Готовая прошивка FPGA |
| [RomEmu_programmer.bgn](RomEmu_programmer.bgn) | Bitgen и DRC |
| [RomEmu_programmer.mrp](RomEmu_programmer.mrp) | Map, ресурсы и предупреждения |
| [RomEmu_programmer.par](RomEmu_programmer.par) | Place & Route |
| [RomEmu_programmer.twr](RomEmu_programmer.twr) | TRACE: setup и hold |
| [RomEmu_programmer.pad](RomEmu_programmer.pad) | Назначения выводов |
| [RomEmu_programmer.prf](RomEmu_programmer.prf) | Ограничения, применённые Diamond |

SHA-256 всех файлов выпуска, включая этот манифест, сохранены в
[SHA256SUMS.txt](SHA256SUMS.txt). Проверка на Mac из корня проекта:

```sh
(cd releases/fpga/programmer-v3 && shasum -a 256 -c SHA256SUMS.txt)
```

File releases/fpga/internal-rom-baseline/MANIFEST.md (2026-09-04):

# Базовая конфигурация с внутренним ПЗУ

**Конфигурация:** `fpga/targets/internal_rom/top.v`

**Микросхема:** `LCMXO2-1200HC-4TG100C`

**Инструмент:** Lattice Diamond 3.14.0.75.2

**Исходный коммит:** `1aeeecbff7d8aaa29a92dd7763e7791884fe3699`

**Время сборки по отчёту Diamond:** 2026-09-02

После сборки исходник был перемещён, а повреждённые комментарии исправлены.
Логика HDL и назначения LPF при этой очистке намеренно не изменялись.

В документации зафиксирована проверка этой конфигурации на реальном Game Boy:
`логотип Nintendo -> чёрный экран`. Результат подтверждает чтение логотипа
загрузочным ПЗУ, но не полное выполнение тестовой программы.

## Файлы

| Файл | SHA-256 |
|---|---|
| `RomEmu_v1_0.jed` | `1fa21e021126ec493a3163f5e19b5198c7db50a52045cf866926d6e97c47248a` |
| `RomEmu_v1_0.twr` | `ca4b5ce83c2d916be91af4b53f71487c6157d52e1fcb3a448c0399d8e65e4029` |
| `RomEmu_v1_0.mrp` | `2ae2c88f069ac6b1528dd843ee697f1c4eb6c505c6287f6fe62a96b35f49b865` |
| `RomEmu_v1_0.bgn` | `86962a388bd12cc7c8ab8bfcfa71f9fdfc8cc7ccad7efe1d18b24db9deb268fe` |

В сохранённых отчётах отсутствуют ошибки отображения логики и DRC при генерации
потока конфигурации. Отчёт временного анализа содержит только проверку путей по
умолчанию, поэтому не доказывает соответствие временным параметрам шины Game Boy.

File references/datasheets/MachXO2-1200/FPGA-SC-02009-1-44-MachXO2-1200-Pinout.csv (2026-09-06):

# Revision 1.41
# 8-Apr-2015
# Revision 1.43 | Added 32QFN
# 21-Oct-2020
# Revision 1.44 | Added WLCSP36
# 16-Nov-2020
PAD | Pin/Ball Function | Bank | Dual Function | Differential | High Speed | DQS | I/O Grouping | TQFP144 | CSBGA132 | TQFP100 | WLCSP25 | QFN32 | WLCSP36
1 | PL2A | 3 | L_GPLLT_FB | True_OF_PL2B | - | - | + | 1 | B1 | - | - | - | -
2 | NC | - | - | - | - | - | + | - | - | - | - | - | -
3 | PL2B | 3 | L_GPLLC_FB | Comp_OF_PL2A | - | - | + | 2 | B2 | - | - | - | -
4 | NC | - | - | - | - | - | + | - | - | - | - | - | -
5 | PL2C | 3 | L_GPLLT_IN | True_OF_PL2D | - | - | + | 3 | C1 | 1 | - | - | C6
6 | PL2D | 3 | L_GPLLC_IN | Comp_OF_PL2C | - | - | + | 4 | C3 | 2 | - | - | B6
7 | NC | - | - | - | - | - | + | - | - | - | - | - | -
8 | PL3A | 3 | PCLKT3_2 | True_OF_PL3B | - | - | + | 5 | C2 | 3 | - | - | -
9 | PL3B | 3 | PCLKC3_2 | Comp_OF_PL3A | - | - | + | 6 | D1 | 4 | - | - | -
10 | NC | - | - | - | - | - | + | - | - | - | - | - | -
11 | VCCIO3 | 3 | - | - | - | - | + | 7 | D3 | 5 | - | - | F6
12 | GND | - | - | - | - | - | - | 8 | D2 | 6 | - | - | -
13 | NC | - | - | - | - | - | - | - | - | - | - | - | -
14 | PL3C | 3 | - | True_OF_PL3D | - | - | - | 9 | E1 | 7 | - | - | -
15 | PL3D | 3 | - | Comp_OF_PL3C | - | - | - | 10 | E2 | 8 | - | - | -
16 | NC | - | - | - | - | - | - | - | - | - | - | - | -
17 | PL4A | 3 | - | True_OF_PL4B | - | - | - | 11 | E3 | 9 | - | - | -
18 | PL4B | 3 | - | Comp_OF_PL4A | - | - | - | 12 | F2 | 10 | - | - | -
19 | PL4C | 3 | - | True_OF_PL4D | - | - | - | 13 | F1 | - | - | - | -
20 | PL4D | 3 | - | Comp_OF_PL4C | - | - | - | 14 | F3 | - | - | - | -
21 | VCCIO3 | 3 | - | - | - | - | - | 16 | G1 | 11 | - | - | -
22 | GND | - | - | - | - | - | + | 18 | G2 | - | - | - | -
23 | PL5A | 3 | PCLKT3_1 | True_OF_PL5B | - | - | + | 19 | G3 | 12 | - | - | -
24 | PL5B | 3 | PCLKC3_1 | Comp_OF_PL5A | - | - | + | 20 | H2 | 13 | - | - | -
25 | PL5C | 3 | - | True_OF_PL5D | - | - | + | 21 | H1 | 14 | - | - | -
26 | PL5D | 3 | - | Comp_OF_PL5C | - | - | + | 22 | H3 | 15 | - | - | -
27 | PL8A | 3 | - | True_OF_PL8B | - | - | + | 23 | J1 | 16 | - | - | -
28 | PL8B | 3 | - | Comp_OF_PL8A | - | - | + | 24 | J2 | 17 | - | - | -
29 | PL8C | 3 | - | True_OF_PL8D | - | - | + | 25 | J3 | 18 | - | - | -
30 | PL8D | 3 | - | Comp_OF_PL8C | - | - | + | 26 | K2 | 19 | - | - | -
31 | PL9A | 3 | PCLKT3_0 | True_OF_PL9B | - | - | + | 27 | K1 | 20 | - | 4 | D6
32 | PL9B | 3 | PCLKC3_0 | Comp_OF_PL9A | - | - | + | 28 | K3 | 21 | - | 5 | E6
33 | NC | - | - | - | - | - | + | - | - | - | - | - | -
34 | GND | - | - | - | - | - | - | 29 | L2 | 22 | - | - | -
35 | VCCIO3 | 3 | - | - | - | - | - | 30 | L1 | 23 | - | 6 | -
36 | PL10A | 3 | - | True_OF_PL10B | - | - | - | 32 | - | - | - | - | -
37 | PL10B | 3 | - | Comp_OF_PL10A | - | - | - | 33 | L3 | - | - | - | -
38 | NC | - | - | - | - | - | - | - | - | - | - | - | -
39 | PL10C | 3 | - | True_OF_PL10D | - | - | - | 34 | M1 | 24 | - | - | -
40 | PL10D | 3 | - | Comp_OF_PL10C | - | - | - | 35 | M2 | 25 | - | - | -
41 | VCC | - | - | - | - | - | - | 36 | N1 | - | - | - | -
42 | VCCIO2 | 2 | - | - | - | - | + | 37 | P1 | 26 | - | 7 | F2
43 | PB4A | 2 | - | True_OF_PB4B | - | - | + | 38 | P2 | - | - | - | -
44 | PB4B | 2 | - | Comp_OF_PB4A | - | - | + | 39 | N2 | - | - | - | -
45 | NC | - | - | - | - | - | + | - | - | - | - | - | -
46 | PB4C | 2 | CSSPIN | True_OF_PB4D | - | - | + | 40 | P3 | 27 | E5 | 8 | E5
47 | PB4D | 2 | - | Comp_OF_PB4C | - | - | + | 41 | M3 | 28 | - | - | -
48 | PB6A | 2 | - | True_OF_PB6B | - | - | + | 42 | N3 | 29 | - | - | -
49 | PB6B | 2 | - | Comp_OF_PB6A | - | - | + | 43 | P4 | 30 | - | - | -
50 | NC | - | - | - | - | - | + | - | - | - | - | - | -
51 | PB6C | 2 | MCLK/CCLK | True_OF_PB6D | - | - | + | 44 | M4 | 31 | D5 | 9 | F5
52 | NC | - | - | - | - | - | + | - | - | - | - | - | -
53 | PB6D | 2 | SO/SPISO | Comp_OF_PB6C | - | - | + | 45 | N4 | 32 | D4 | 10 | E4
54 | GND | - | - | - | - | - | - | 46 | P5 | 33 | - | - | -
55 | PB9C | 2 | - | True_OF_PB9D | - | - | - | 47 | N5 | - | - | - | -
56 | PB9D | 2 | - | Comp_OF_PB9C | - | - | - | 48 | M5 | - | - | - | -
57 | NC | - | - | - | - | - | - | - | - | - | - | - | -
58 | PB9A | 2 | PCLKT2_0 | True_OF_PB9B | - | - | - | 49 | N6 | 34 | E4 | 11 | E3
59 | PB9B | 2 | PCLKC2_0 | Comp_OF_PB9A | - | - | - | 50 | P6 | 35 | - | 12 | F4
60 | NC | - | - | - | - | - | - | - | - | - | - | - | -
61 | VCCIO2 | 2 | - | - | - | - | - | 51 | M6 | - | C4 | - | -
62 | PB11C | 2 | - | True_OF_PB11D | - | - | - | 52 | P7 | 36 | - | - | -
63 | GND | - | - | - | - | - | + | 53 | - | - | - | - | -
64 | PB11D | 2 | - | Comp_OF_PB11C | - | - | + | 54 | N7 | 37 | - | - | -
65 | NC | - | - | - | - | - | + | - | - | - | - | - | -
66 | PB11A | 2 | PCLKT2_1 | True_OF_PB11B | - | - | + | 55 | M7 | 38 | E3 | 13 | E2
67 | PB11B | 2 | PCLKC2_1 | Comp_OF_PB11A | - | - | + | 56 | N8 | 39 | - | 14 | F3
68 | PB15A | 2 | - | True_OF_PB15B | - | - | + | 57 | P8 | 40 | - | - | -
69 | PB15B | 2 | - | Comp_OF_PB15A | - | - | + | 58 | M8 | 41 | - | - | -
70 | PB15C | 2 | - | True_OF_PB15D | - | - | + | 59 | P9 | - | - | - | -
71 | PB15D | 2 | - | Comp_OF_PB15C | - | - | + | 60 | N9 | - | - | - | -
72 | PB18A | 2 | - | True_OF_PB18B | - | - | + | 61 | M9 | 42 | - | - | -
73 | PB18B | 2 | - | Comp_OF_PB18A | - | - | + | 62 | N10 | 43 | - | - | -
74 | NC | - | - | - | - | - | + | - | - | - | - | - | -
75 | GND | - | - | - | - | - | - | 64 | P10 | 44 | D3 | - | -
76 | PB18C | 2 | - | True_OF_PB18D | - | - | - | 65 | M10 | 45 | - | - | -
77 | VCCIO2 | 2 | - | - | - | - | - | 66 | N11 | 46 | - | 15 | -
78 | NC | - | - | - | - | - | - | - | - | - | - | - | -
79 | PB18D | 2 | - | Comp_OF_PB18C | - | - | - | 67 | P11 | 47 | - | - | -
80 | PB20A | 2 | - | True_OF_PB20B | - | - | - | 68 | M11 | - | - | - | -
81 | PB20B | 2 | - | Comp_OF_PB20A | - | - | - | 69 | P12 | - | - | - | -
82 | NC | - | - | - | - | - | - | - | - | - | - | - | -
83 | PB20C | 2 | SN | True_OF_PB20D | - | - | - | 70 | N12 | 48 | E2 | 16 | E1
84 | NC | - | - | - | - | - | - | - | - | - | - | - | -
85 | PB20D | 2 | SI/SISPI | Comp_OF_PB20C | - | - | - | 71 | P13 | 49 | E1 | 17 | F1
86 | VCC | - | - | - | - | - | - | 72 | P14 | 50 | D1 | 18 | C1
87 | PR10D | 1 | - | Comp_OF_PR10C | - | DQ1 | + | 73 | N14 | 51 | - | - | -
88 | PR10C | 1 | - | True_OF_PR10D | - | DQ1 | + | 74 | N13 | 52 | - | - | -
89 | PR10B | 1 | - | Comp_OF_PR10A | - | DQ1 | + | 75 | M14 | - | - | - | -
90 | PR10A | 1 | - | True_OF_PR10B | - | DQ1 | + | 76 | M12 | - | - | - | -
91 | PR9D | 1 | - | Comp_OF_PR9C | - | DQ1 | + | 77 | M13 | 53 | - | - | -
92 | PR9C | 1 | - | True_OF_PR9D | - | DQ1 | + | 78 | L14 | 54 | - | - | -
93 | VCCIO1 | 1 | - | - | - | - | + | 79 | L12 | 55 | - | 19 | -
94 | GND | - | - | - | - | - | - | 80 | L13 | 56 | - | - | -
95 | PR9B | 1 | - | Comp_OF_PR9A | - | DQ1 | - | 81 | K14 | 57 | - | - | -
96 | PR9A | 1 | - | True_OF_PR9B | - | DQ1 | - | 82 | K13 | 58 | - | - | -
97 | PR8D | 1 | - | Comp_OF_PR8C | - | DQ1 | - | 83 | K12 | 59 | - | - | -
98 | PR8C | 1 | - | True_OF_PR8D | - | DQ1 | - | 84 | J13 | 60 | - | - | -
99 | PR8B | 1 | - | Comp_OF_PR8A | - | DQS1N | - | 85 | J14 | - | - | - | -
100 | PR8A | 1 | - | True_OF_PR8B | - | DQS1 | - | 86 | J12 | 61 | - | - | -
101 | VCCIO1 | 1 | - | - | - | - | - | 88 | H14 | - | - | - | -
102 | NC | - | - | - | - | - | - | - | - | - | - | - | -
103 | GND | - | - | - | - | - | + | 90 | H13 | - | - | - | -
104 | PR5D | 1 | PCLKC1_0 | Comp_OF_PR5C | - | DQ0 | + | 91 | H12 | 62 | - | 20 | -
105 | PR5C | 1 | PCLKT1_0 | True_OF_PR5D | - | DQ0 | + | 92 | G13 | 63 | - | 21 | -
106 | PR5B | 1 | - | Comp_OF_PR5A | - | DQS0N | + | 93 | G14 | 64 | - | - | -
107 | PR5A | 1 | - | True_OF_PR5B | - | DQS0 | + | 94 | G12 | 65 | - | - | -
108 | PR4D | 1 | - | Comp_OF_PR4C | - | DQ0 | + | 95 | F14 | 66 | - | - | -
109 | NC | - | - | - | - | - | + | - | - | - | - | - | -
110 | PR4C | 1 | - | True_OF_PR4D | - | DQ0 | + | 96 | F13 | 67 | - | - | -
111 | PR4B | 1 | - | Comp_OF_PR4A | - | DQ0 | + | 97 | F12 | 68 | - | - | -
112 | NC | - | - | - | - | - | + | - | - | - | - | - | -
113 | PR4A | 1 | - | True_OF_PR4B | - | DQ0 | + | 98 | E13 | 69 | - | - | -
114 | PR3B | 1 | - | Comp_OF_PR3A | - | DQ0 | + | 99 | E14 | 70 | - | - | -
115 | NC | - | - | - | - | - | + | - | - | - | - | - | -
116 | PR3A | 1 | - | True_OF_PR3B | - | DQ0 | + | 100 | E12 | 71 | - | - | -
117 | GND | - | - | - | - | - | - | 101 | D13 | 72 | - | - | -
118 | NC | - | - | - | - | - | - | - | - | - | - | - | -
119 | VCCIO1 | 1 | - | - | - | - | - | 102 | D14 | 73 | - | - | -
120 | PR2D | 1 | - | Comp_OF_PR2C | - | DQ0 | - | 104 | D12 | - | - | - | -
121 | PR2C | 1 | - | True_OF_PR2D | - | DQ0 | - | 105 | C14 | - | - | - | -
122 | PR2B | 1 | - | Comp_OF_PR2A | - | DQ0 | - | 106 | C13 | 74 | - | - | -
123 | NC | - | - | - | - | - | - | - | - | - | - | - | -
124 | PR2A | 1 | - | True_OF_PR2B | - | DQ0 | - | 107 | B14 | 75 | - | - | -
125 | VCC | - | - | - | - | - | - | 108 | A14 | - | - | - | -
126 | PT17D | 0 | DONE | Comp_OF_PT17C | - | - | + | 109 | A13 | 76 | B1 | 23 | A1
127 | NC | - | - | - | - | - | + | - | - | - | - | - | -
128 | PT17C | 0 | INITN | True_OF_PT17D | - | - | + | 110 | B13 | 77 | A1 | - | B1
129 | PT17B | 0 | - | Comp_OF_PT17A | TRUE | - | + | 111 | A12 | - | - | - | -
130 | NC | - | - | - | - | - | + | - | - | - | - | - | -
131 | PT17A | 0 | - | True_OF_PT17B | TRUE | - | + | 112 | C12 | - | - | - | -
132 | PT16D | 0 | - | Comp_OF_PT16C | - | - | + | 113 | B12 | - | - | - | -
133 | PT16C | 0 | - | True_OF_PT16D | - | - | + | 114 | A11 | 78 | - | - | -
134 | NC | - | - | - | - | - | + | - | - | - | - | - | -
135 | PT16B | 0 | - | Comp_OF_PT16A | TRUE | - | + | 115 | C11 | - | - | - | -
136 | GND | - | - | - | - | - | - | 116 | B11 | 79 | - | - | -
137 | PT16A | 0 | - | True_OF_PT16B | TRUE | - | - | 117 | A10 | - | C1 | - | -
138 | VCCIO0 | 0 | - | - | - | - | - | 118 | B10 | 80 | - | 24 | A3
139 | NC | - | - | - | - | - | - | - | - | - | - | - | -
140 | PT15D | 0 | PROGRAMN | Comp_OF_PT15C | - | - | - | 119 | C10 | 81 | A2 | 25 | A2
141 | PT15C | 0 | JTAGENB | True_OF_PT15D | - | - | - | 120 | B9 | 82 | B2 | 26 | B2
142 | NC | - | - | - | - | - | - | - | - | - | - | - | -
143 | PT15B | 0 | - | Comp_OF_PT15A | TRUE | - | - | 121 | A9 | 83 | - | - | -
144 | PT15A | 0 | - | True_OF_PT15B | TRUE | - | - | 122 | C9 | 84 | - | - | -
145 | NC | - | - | - | - | - | - | - | - | - | - | - | -
146 | VCCIO0 | 0 | - | - | - | - | - | 123 | A8 | - | C2 | - | -
147 | GND | - | - | - | - | - | + | 124 | - | - | - | - | -
148 | NC | - | - | - | - | - | + | - | - | - | - | - | -
149 | PT12D | 0 | SDA/PCLKC0_0 | Comp_OF_PT12C | - | - | + | 125 | B8 | 85 | A3 | 27 | C2
150 | PT12C | 0 | SCL/PCLKT0_0 | True_OF_PT12D | - | - | + | 126 | C8 | 86 | B3 | 28 | D2
151 | NC | - | - | - | - | - | + | - | - | - | - | - | -
152 | PT12B | 0 | PCLKC0_1 | Comp_OF_PT12A | TRUE | - | + | 127 | B7 | 87 | - | - | B3
153 | PT12A | 0 | PCLKT0_1 | True_OF_PT12B | TRUE | - | + | 128 | A7 | 88 | D2 | - | A4
154 | NC | - | - | - | - | - | + | - | - | - | - | - | -
155 | NC | - | - | - | - | - | + | - | - | - | - | - | -
156 | NC | - | - | - | - | - | + | - | - | - | - | - | -
157 | PT11D | 0 | TMS | Comp_OF_PT11C | - | - | + | 130 | A6 | 90 | B4 | 29 | C3
158 | PT11C | 0 | TCK | True_OF_PT11D | - | - | + | 131 | B6 | 91 | A4 | 30 | D3
159 | NC | - | - | - | - | - | + | - | - | - | - | - | -
160 | PT11B | 0 | - | Comp_OF_PT11A | TRUE | - | + | 132 | C6 | - | - | - | -
161 | PT11A | 0 | - | True_OF_PT11B | TRUE | - | + | 133 | B5 | - | - | - | -
162 | NC | - | - | - | - | - | + | - | - | - | - | - | -
163 | GND | - | - | - | - | - | - | 134 | A5 | 92 | C3 | - | -
164 | VCCIO0 | 0 | - | - | - | - | - | 135 | C5 | 93 | - | 31 | -
165 | NC | - | - | - | - | - | - | - | - | - | - | - | -
166 | PT10D | 0 | TDI | Comp_OF_PT10C | - | - | - | 136 | B4 | 94 | C5 | 32 | A5
167 | PT10C | 0 | TDO | True_OF_PT10D | - | - | - | 137 | A4 | 95 | A5 | 1 | B4
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

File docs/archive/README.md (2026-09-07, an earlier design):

# Архив документации

Файлы в этом каталоге сохранены только как исторические снимки. Они могут
содержать устаревшие номера выводов, номиналы и отметки комплектации.

`bom-2026-09-04.md` — прежний ручной план комплектации с таблицами соединений
и расчётами пассивных компонентов. Сохранён без актуализации для истории.

`misc-components-legacy.csv` — ранний ручной перечень компонентов, который
дублировал BOM и не был синхронизирован со схемой автоматически.

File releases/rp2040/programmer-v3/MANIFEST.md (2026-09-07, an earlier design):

# RP2040 programmer v3 — 2026-09-07

Собран `gb_cart_programmer.uf2` для Waveshare RP2040-Zero, версия 3.0.
Бинарный USB, блоки до 1024 байт, SPI 4 МГц. Совместим только с FPGA
`programmer` протокола 3.0. Аппаратная приёмка не выполнена.

## Происхождение

- Базовый коммит: `6a8694a745d329f05bdbe1f1d615b8bdba3c4be7`.
- Сборка выполнена с незакоммиченными изменениями. Точные исходники прошивки,
  FPGA и утилиты Mac сохранены в `source/`; контрольные суммы всех файлов,
  включая UF2 и манифест, — в `SHA256SUMS.txt`.
- Pico SDK 2.3.1: `079c6f39023649b154152db30f1d781e884879bc`.
- TinyUSB: `86ad6e56c1700e85f1c5678607a762cfe3aa2f47`.
- picotool: `2041936441b48a3cc53ae3da9e805229fe8f4e18`.
- ARM GCC 9.2.1; Release; `-Wall -Wextra -Werror`.

Из корня проекта с SDK в `/Users/kkk/pico-sdk`:

```sh
PICO_SDK_PATH=/Users/kkk/pico-sdk cmake -S firmware/rp2040/programmer -B firmware/rp2040/programmer/build-v3 -DPICO_BOARD=waveshare_rp2040_zero -DCMAKE_BUILD_TYPE=Release
cmake --build firmware/rp2040/programmer/build-v3 -j4
```

## Проверка

- Сборка RP2040 завершена; picotool подтвердил версию 3.0, плату, SDK и USB stdio.
- 10 host-тестов и тест фактического C-кода моста с моделью SPI — PASS.
- RTL v3 при SPI 4 МГц и тактах FPGA около 42,55/53,19/64 МГц — PASS.
- Регрессия RTL v2 с общим контроллером шины — PASS.
- JEDEC в выпуск не входит. Map, EBR inference, timing и размещение в MachXO2
  ещё требуют проверки в Diamond. Полный дамп, запись ROM и аппаратная скорость
  не проверены. UF2 не является подтверждением работы стенда.

[Инструкция для Mac](../../../docs/PROGRAMMER.md).

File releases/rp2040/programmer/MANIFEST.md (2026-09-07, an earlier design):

# RP2040 programmer v2 — 2026-09-07

`gb_cart_programmer.uf2` собран для Waveshare RP2040-Zero. Аппаратно не проверен.
Совместим только с новой FPGA-конфигурацией `programmer`, протокол 2.0.
Старый JEDEC `flash-bringup-pass` команд программатора не поддерживает.

- Pico SDK 2.2.0: `a1438dff1d38bd9c65dbd693f0e5db4b9ae91779`.
- TinyUSB: `86ad6e56c1700e85f1c5678607a762cfe3aa2f47`.
- ARM GCC 9.2.1; Release; `-Wall -Wextra -Werror`.
- picotool 2.2.0: `a7eb3988f0645239185fadb4e25d8279478c2dbb`.
- Исходники прошивки сохранены в `source/`; суммы в `SHA256SUMS.txt`.

При локальной сборке SDK был в `/private/tmp/gb-cart-pico-sdk`.
Сначала CMake с `-DPICO_BOARD=waveshare_rp2040_zero -DPICO_NO_PICOTOOL=1`,
затем `cmake --build ... -j4` и преобразование ELF официальным picotool:

```sh
picotool uf2 convert gb_cart_programmer.elf gb_cart_programmer.uf2 --family rp2040
picotool info -a gb_cart_programmer.uf2
```

Метаданные UF2 подтверждают `gb_cart_programmer`, USB stdin/stdout, правильную
плату и SDK. Это не проверка реального USB или SPI.

[Инструкция запуска](../../../docs/PROGRAMMER.md). JEDEC программатора ещё
нужно собрать в Diamond и проверить timing/назначения выводов.

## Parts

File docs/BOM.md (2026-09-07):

# Комплектация

Актуальный перечень установленных компонентов и номиналов следует выгружать
из [схемы KiCad](../hardware/cartridge/cartridge.kicad_sch).
Проверенного производственного BOM в репозитории пока нет.

Основные компоненты проекта: MachXO2 `LCMXO2-1200HC-4TG100C`, Flash
`MX29LV320E`, F-RAM `FM28V100-TG`, модуль `RP2040-Zero` и четыре
`SN74LVC8T245PWR`. Точный вариант, корпус, количество пассивных компонентов
и признаки DNP необходимо брать из схемы перед закупкой.

[Ручной план от 2026-09-04](archive/bom-2026-09-04.md) перенесён в архив:
он содержит условные обозначения и соединения, не синхронизируемые со схемой.
Его количества и назначения выводов не являются актуальным списком закупки.
Финальная комплектация питания остаётся открытым вопросом.

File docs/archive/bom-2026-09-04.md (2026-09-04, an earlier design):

# FPGA-картридж с Flash-памятью для Game Boy — заметки по комплектации

**Обновлено:** 2026-09-04

> Этот файл содержит план комплектации, расчёты количества и пояснения для
> закупки.

---

## 1. Основные компоненты

| Обозначение | Компонент | Модель | Примечания |
|---|---|---|---|
| FPGA | FPGA | `LCMXO2-1200HC-4TG100C` | Lattice MachXO2, TQFP-100 |
| ROM | Flash-память ПЗУ | `MX29LV320E T/B` | 32 Мбит / 4 МБ, режим x8 |
| FRAM | Память сохранений | `FM28V100-TG` | 1 Мбит / 128 КБ |
| MCU | Микроконтроллер/модуль USB | `RP2040-Zero` | USB, программирование и сохранения |
| U1 | Преобразователь уровней | `SN74LVC8T245PWR` | Адреса A0-A7 |
| U2 | Преобразователь уровней | `SN74LVC8T245PWR` | Адреса A8-A15 |
| U3 | Преобразователь уровней | `SN74LVC8T245PWR` | Данные D0-D7 |
| U4 | Преобразователь уровней | `SN74LVC8T245PWR` | Управляющие сигналы |

---

## 2. FPGA

### Развязывающие конденсаторы

| Обозначение | Номинал | Подключение | Назначение |
|---|---|---|---|
| C_FPGA1 | 100 нФ X7R | вывод 50 FPGA VCC → GND | развязка ядра |
| C_FPGA2 | 100 нФ X7R | вывод 100 FPGA VCC → GND | развязка ядра |
| C_IO30 | 100 нФ X7R | вывод 5 FPGA VCCIO3 → GND | банк 3 |
| C_IO31 | 100 нФ X7R | вывод 11 FPGA VCCIO3 → GND | банк 3 |
| C_IO32 | 100 нФ X7R | вывод 23 FPGA VCCIO3 → GND | банк 3 |
| C_IO20 | 100 нФ X7R | вывод 26 FPGA VCCIO2 → GND | банк 2 |
| C_IO21 | 100 нФ X7R | вывод 46 FPGA VCCIO2 → GND | банк 2 |
| C_IO10 | 100 нФ X7R | вывод 55 FPGA VCCIO1 → GND | банк 1 |
| C_IO11 | 100 нФ X7R | вывод 73 FPGA VCCIO1 → GND | банк 1 |
| C_IO00 | 100 нФ X7R | вывод 80 FPGA VCCIO0 → GND | банк 0 |
| C_IO01 | 100 нФ X7R | вывод 93 FPGA VCCIO0 → GND | банк 0 |

### Накопительные конденсаторы

| Обозначение | Номинал | Подключение | Назначение |
|---|---|---|---|
| C_CORE_B1 | 10 мкФ X5R/X7R | VCC 3,3 В → GND возле FPGA | накопительный VCC |
| C_CORE_B2 | 10 мкФ X5R/X7R | VCC 3,3 В → GND возле FPGA | накопительный VCC |
| C_B0 | 10 мкФ | VCCIO0 → GND | накопительный, банк 0 |
| C_B1 | 10 мкФ | VCCIO1 → GND | накопительный, банк 1 |
| C_B2 | 10 мкФ | VCCIO2 → GND | накопительный, банк 2 |
| C_B3 | 10 мкФ | VCCIO3 → GND | накопительный, банк 3 |

### Резисторы конфигурации и JTAG

| Обозначение | Номинал | Подключение | Назначение |
|---|---|---|---|
| R_TCK | 4,7 кОм | вывод 91 FPGA TCK → GND | подтяжка вниз по рекомендации Lattice |
| R_PROGRAM | 4,7 кОм | вывод 81 FPGA PROGRAMN → 3,3 В | устойчивый запуск |
| R_INIT | 4,7 кОм | вывод 77 FPGA INITN → 3,3 В | подтяжка конфигурации вверх |
| R_DONE | 4,7 кОм | вывод 76 FPGA DONE → 3,3 В | подтяжка конфигурации вверх |
| R_JTAGEN | 10 кОм | вывод 82 FPGA JTAGENB → 3,3 В | включение режима JTAG |

---

## 3. FRAM

**Модель:** `FM28V100-TG`

### Конденсаторы

| Обозначение | Номинал | Подключение | Назначение |
|---|---|---|---|
| C_FRAM | 100 нФ | вывод 8 VDD → вывод 24 VSS | развязка питания |
| C_FRAM_BULK | 1 мкФ | вывод 8 VDD → вывод 24 VSS | локальный накопительный |

### Подтягивающие резисторы

| Обозначение | Номинал | Подключение | Назначение |
|---|---|---|---|
| R_FRAM_CE | 10 кОм | вывод 30 CE1 → 3,3 В | отключение при запуске |
| R_FRAM_WE | 10 кОм | вывод 5 WE → 3,3 В | защита от случайной записи |
| R_FRAM_OE | 10 кОм, DNP | вывод 32 OE → 3,3 В | необязательная установка |

### Постоянные соединения

| Сигнал | Подключение | Назначение |
|---|---|---|
| CE2 | вывод 6 F-RAM → 3,3 В | CE2 постоянно активен |

---

## 4. Flash-память ПЗУ

**Модель:** `MX29LV320E T/B`

### Конденсаторы

| Обозначение | Номинал | Подключение | Назначение |
|---|---|---|---|
| C_ROM | 100 нФ | вывод 37 VCC → выводы 27/46 GND | развязка питания |
| C_ROM_BULK | 1 мкФ | вывод 37 VCC → GND | локальный накопительный |

### Подтягивающие резисторы

| Обозначение | Номинал | Подключение | Назначение |
|---|---|---|---|
| R_ROM_CE | 10 кОм | вывод 26 CE# → 3,3 В | отключение Flash при запуске |
| R_ROM_WE | 10 кОм | вывод 11 WE# → 3,3 В | запись неактивна |
| R_ROM_RST | 10 кОм | вывод 12 RESET# → 3,3 В | обычный режим чтения |
| R_ROM_RYBY | 10 кОм | вывод 15 RY/BY# → 3,3 В | подтяжка выхода с открытым стоком |
| R_ROM_OE | 10 кОм, DNP | вывод 28 OE# → 3,3 В | необязательная установка |

### Постоянные соединения

| Сигнал | Подключение | Назначение |
|---|---|---|
| BYTE# | вывод 47 → GND | выбор режима x8 |
| WP#/ACC | вывод 14 → 3,3 В | обычный режим, ACC отключён |

---

## 5. Преобразователи уровней

**Модель:** `SN74LVC8T245PWR`

---

### U1 — адреса A0-A7

| Обозначение | Номинал | Подключение | Назначение |
|---|---|---|---|
| C_U1_A | 100 нФ | вывод 1 U1 VCCA → GND | развязка стороны 3,3 В |
| C_U1_B | 100 нФ | выводы 23+24 U1 VCCB → GND | развязка стороны 5 В |

Постоянное соединение:

```text
вывод 2 U1 DIR → GND
```

Направление: постоянное `B → A`.

---

### U2 — адреса A8-A15

| Обозначение | Номинал | Подключение | Назначение |
|---|---|---|---|
| C_U2_A | 100 нФ | вывод 1 U2 VCCA → GND | развязка стороны 3,3 В |
| C_U2_B | 100 нФ | выводы 23+24 U2 VCCB → GND | развязка стороны 5 В |

Постоянное соединение:

```text
вывод 2 U2 DIR → GND
```

Направление: постоянное `B → A`.

---

### U3 — данные D0-D7

| Обозначение | Номинал | Подключение | Назначение |
|---|---|---|---|
| C_U3_A | 100 нФ | вывод 1 U3 VCCA → GND | шина данных, сторона 3,3 В |
| C_U3_B | 100 нФ | выводы 23+24 U3 VCCB → GND | шина данных, сторона 5 В |
| R_U3_OE | 10 кОм | вывод 22 U3 OE → 3,3 В | высокоимпедансное состояние при запуске |
| R_U3_DIR | 10 кОм | вывод 2 U3 DIR → GND | по умолчанию Game Boy → FPGA |

В дальнейшем FPGA активно управляет `DIR` сигналом `data_dir`.

---

### U4 — управляющие сигналы

| Обозначение | Номинал | Подключение | Назначение |
|---|---|---|---|
| C_U4_A | 100 нФ | вывод 1 U4 VCCA → GND | развязка стороны 3,3 В |
| C_U4_B | 100 нФ | выводы 23+24 U4 VCCB → GND | развязка стороны 5 В |

Постоянное соединение:

```text
вывод 2 U4 DIR → GND
```

Направление: постоянное `B → A`.

---

## 6. Общие конденсаторы питания

| Обозначение | Номинал | Подключение | Назначение |
|---|---|---|---|
| C_5V_BULK | 10 мкФ | 5V_GB → GND возле преобразователей | общий накопительный 5 В |
| C_3V3_BULK | 10 мкФ | 3V3 → GND возле памяти и преобразователей | общий накопительный 3,3 В |

---

## 7. Интерфейс RP2040 / FPGA

| Обозначение | Номинал | Подключение | Назначение |
|---|---|---|---|
| R_RP_CS | 10 кОм | RP2040 → FPGA CS# → 3,3 В | SPI неактивен при сбросе |

Финальный интерфейс RP2040 ↔ FPGA ещё должен быть зафиксирован.

---

## 8. Необязательные светодиоды

| Обозначение | Номинал | Подключение | Назначение |
|---|---|---|---|
| R_LED_OK | 1 кОм | GPIO FPGA → светодиод → GND | необязательный индикатор состояния |
| R_LED_ERR | 1 кОм | GPIO FPGA → светодиод → GND | необязательный индикатор ошибки |

---

## 9. Компоненты DNP

`DNP` означает: посадочное место добавить на PCB, но компонент по умолчанию не
устанавливать.

| Обозначение | Номинал | Назначение |
|---|---|---|
| R_FRAM_OE | 10 кОм | необязательная подтяжка OE F-RAM |
| R_ROM_OE | 10 кОм | необязательная подтяжка OE Flash |

---

## 10. Сводка пассивных компонентов

### 100 нФ

- FPGA: 11 × 100 нФ X7R
- F-RAM: 1 × 100 нФ
- Flash: 1 × 100 нФ
- преобразователи уровней: 8 × 100 нФ

**Всего: 21 × 100 нФ**

### 1 мкФ

- F-RAM: 1
- Flash: 1

**Всего: 2 × 1 мкФ**

### 10 мкФ

- накопительные конденсаторы ядра FPGA: 2
- банки VCCIO FPGA: 4
- линия 5 В: 1
- линия 3,3 В: 1

**Всего: 8 × 10 мкФ**

### 4,7 кОм

- R_TCK
- R_PROGRAM
- R_INIT
- R_DONE

**Всего: 4 × 4,7 кОм**

### 10 кОм, устанавливаемые

- R_JTAGEN
- R_FRAM_CE
- R_FRAM_WE
- R_ROM_CE
- R_ROM_WE
- R_ROM_RST
- R_ROM_RYBY
- R_U3_OE
- R_U3_DIR
- R_RP_CS

**Всего: 10 × 10 кОм**

### 10 кОм, DNP

- R_FRAM_OE
- R_ROM_OE

**Всего: 2 посадочных места**

### 1 кОм, необязательные

- R_LED_OK
- R_LED_ERR

**Всего: 2 × 1 кОм, необязательные**

---

## 11. Примечания

- Развязывающие конденсаторы размещать максимально близко к соответствующим
  выводам питания.
- Для DNP-компонентов оставить посадочные места на PCB.
- `BYTE#` Flash подключён к GND для режима x8.
- `CE2` F-RAM постоянно подключён к 3,3 В.
- `DIR` U1/U2/U4 постоянно подключён к GND.
- U3 имеет управляемые FPGA сигналы `DIR` и `OE`.
- Перед завершением PCB электрические подключения необходимо ещё раз сверить с
  технической документацией выбранных корпусов микросхем.

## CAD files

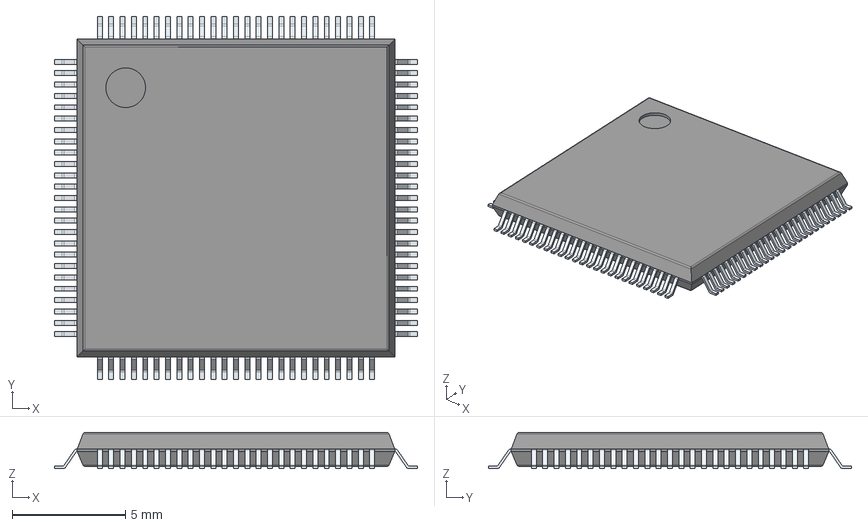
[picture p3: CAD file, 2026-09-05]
hardware/cartridge/3dmodels/LCMXO2-1200HC-4TG100C.stp
16.0 x 16.0 x 1.60 mm
PinsArrayLR
PinsArrayTB

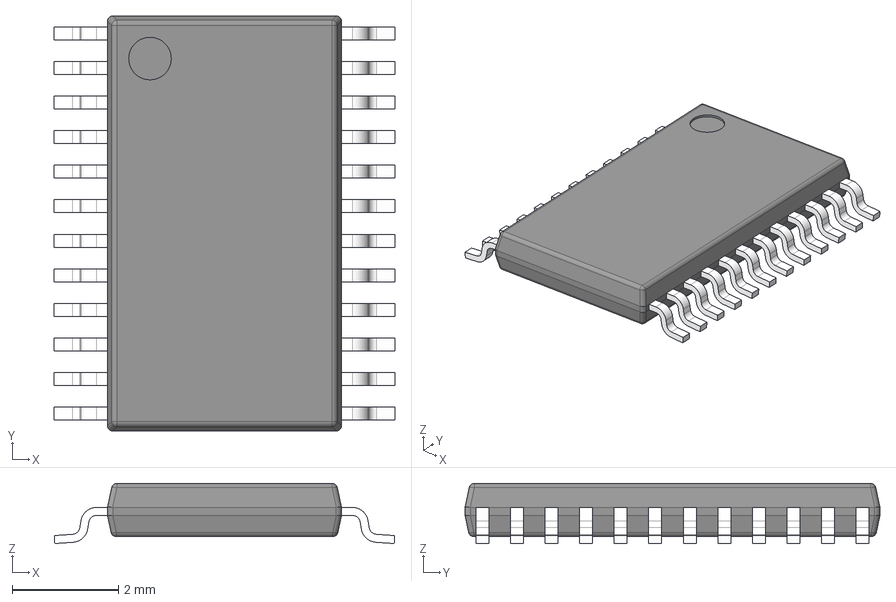
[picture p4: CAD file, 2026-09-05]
hardware/cartridge/3dmodels/SN74LVC8T245PWR.stp
6.40 x 7.80 x 1.13 mm
BODY-TSSOP
LEAD-TSSOP x 24
PIN1

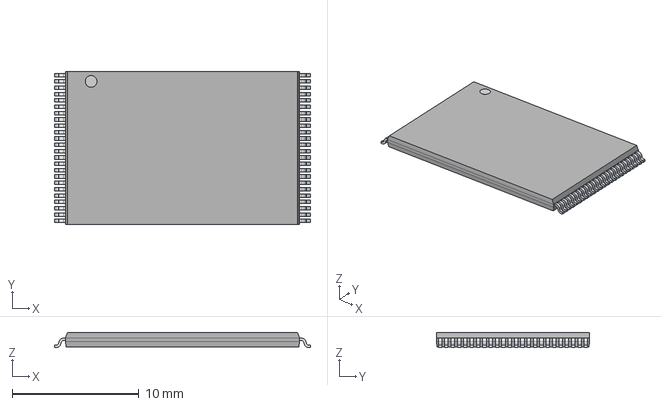
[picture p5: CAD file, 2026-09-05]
hardware/cartridge/3dmodels/MX29LV320EBTI-70G.stp
20.2 x 12.1 x 1.20 mm

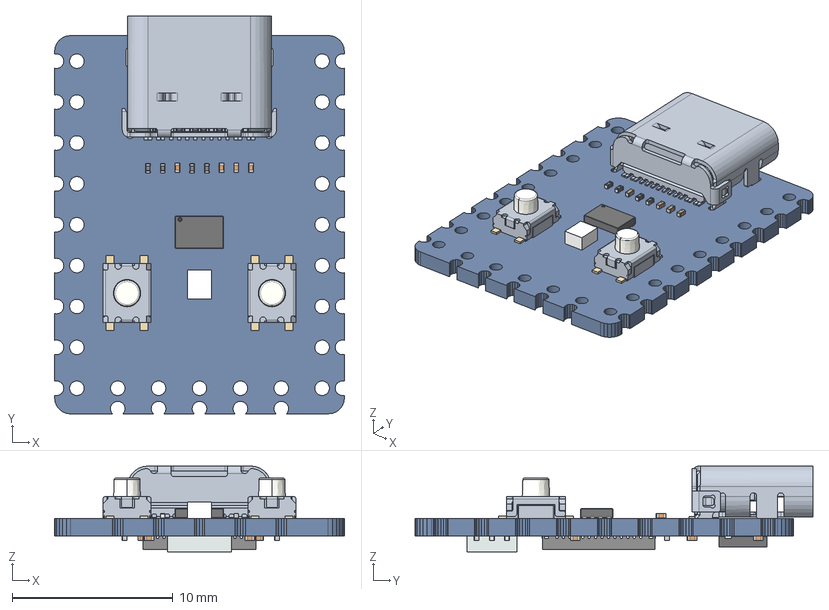
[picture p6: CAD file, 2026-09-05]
hardware/cartridge/3dmodels/RP2040_Zero.stp
18.0 x 24.7 x 5.34 mm
BOARD
ANSCHL_X_FCSSE_1 x 9
K_X_F6RPER_1 x 9
EXTRUDED-32530
USER_LIBRARY-CHIP_CAP_MLCC_0201 x 19
EXTRUDED-36548
USER_LIBRARY-RP2040_QFN56_04
USER_LIBRARY-8MA3_1
USER_LIBRARY-8MA3_2
EXTRUDED-175432
EXTRUDED-175804 x 5
TS-1185EC-A-E-A-1 x 2
EXTRUDED-374538 x 10

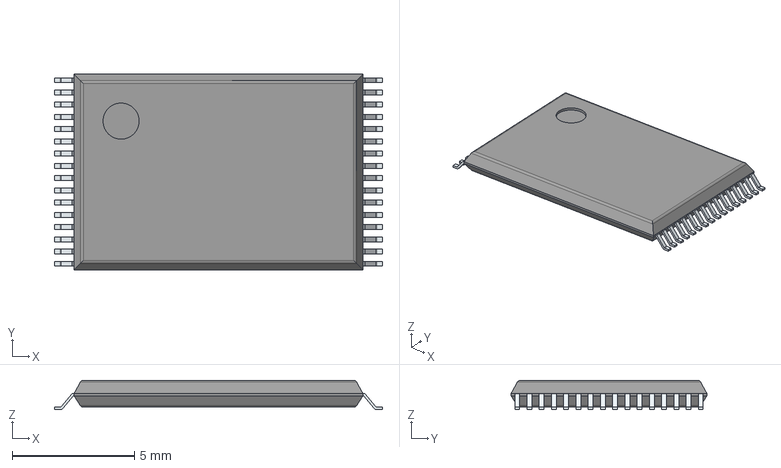
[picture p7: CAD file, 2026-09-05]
hardware/cartridge/3dmodels/FM28V100-TG.stp
13.4 x 8.00 x 1.20 mm
PinsArrayLR

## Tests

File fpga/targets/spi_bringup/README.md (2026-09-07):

# SPI bring-up

Готовая рабочая сборка: [JEDEC, отчёты и манифест](../../../releases/fpga/spi_bringup/MANIFEST.md).

Отдельная конфигурация MachXO2 для запроса версии с RP2040-Zero.
Подключение и параметры обмена определены в [протоколе 1.0](../../../docs/SPI_BRINGUP.md).

Входы проходят двухступенчатую синхронизацию на внутренние 2,08 МГц.
На старте используется явная цепочка FD1S3AX. Обмен смоделирован на частоте
из спецификации; аппаратная работа подтверждена в
[журнале испытаний](../../../docs/TEST_PLAN.md#журнал-результатов).

Flash CE#/OE#/WE# постоянно HIGH, адрес равен нулю, D-шина освобождена
и её подтяжки отключены. Game Boy при этом эксперименте отключён.
Данные Flash не читаются и не изменяются.

## Индикация

**Индикация отличается от Flash-теста.** Pin 82 поднимается после стартового
сброса. Pin 83 поднимается после 72 тактов кадра GET_VERSION и остаётся HIGH
до перезапуска FPGA. Это признак отправленного ответа, а не подтверждение
его правильного приёма RP2040. Неизвестные и неполные запросы не устанавливают
этот признак; уже установленный признак они не сбрасывают.

## Сборка

В Diamond открыть `fpga/diamond/RomEmu.ldf`, выбрать implementation
`spi_bringup`, выполнить синтез, Map, Place & Route и экспорт JEDEC.
По умолчанию активна другая конфигурация — `flash_bringup`.

Альтернативно, из корня репозитория:

```powershell
powershell -NoProfile -ExecutionPolicy Bypass -File fpga/targets/spi_bringup/build.ps1
```

Параметр `-DiamondRoot` позволяет указать каталог Diamond; по умолчанию
`C:/lscc/diamond/3.14`. Результат:
`fpga/diamond/spi_bringup/RomEmu_spi_bringup.jed`.
Рядом формируются отчёты `.pad`, `.mrp`, `.twr` и `.bgn`.

## Проверка

Из `fpga/tests/build` (создать каталог при первом запуске):

```powershell
& C:/lscc/diamond/3.14/questasim/win64/vsim.exe -c -do ../spi_bringup.do
& C:/lscc/diamond/3.14/questasim/win64/vsim.exe -c -do 'set netlist 1; do ../spi_bringup.do'
```

Вторая команда требует предварительной сборки: используется `top_prim.v`
и библиотека примитивов MachXO2. Обе проверки моделируют обмен через внешние
порты: старт, сигнатуру, 71 длину прерванного кадра, неизвестную команду,
лишние байты за пределами счётчика и восстановление следующим запросом.
Проверяются освобождение MISO и неактивность Flash.

Ранее зафиксированные результаты симуляции и сборки — в
[журнале испытаний](../../../docs/TEST_PLAN.md#журнал-результатов).
Проверка времён не заменяет аппаратную проверку асинхронного SPI.
Для неё использовать [прошивку RP2040](../../../firmware/rp2040/spi_bringup/README.md)
и [процедуру приёмки](../../../docs/SPI_BRINGUP.md#аппаратная-приёмка).

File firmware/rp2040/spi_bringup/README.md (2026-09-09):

# RP2040 SPI bring-up

Прошивка Waveshare RP2040-Zero: USB CDC-консоль и ведущий SPI0 для проверки
связи с [FPGA spi_bringup](../../../fpga/targets/spi_bringup/README.md).
[Подключение, питание и протокол](../../../docs/SPI_BRINGUP.md) описаны отдельно.
Команд чтения и изменения Flash нет.

## Сборка

Требуются Raspberry Pi Pico SDK, CMake, компилятор ARM embedded и инструмент
сборки, выбранный CMake. Переменная `PICO_SDK_PATH` должна указывать на SDK.
Из корня репозитория:

```sh
cmake -S firmware/rp2040/spi_bringup -B firmware/rp2040/spi_bringup/build -DPICO_BOARD=waveshare_rp2040_zero
cmake --build firmware/rp2040/spi_bringup/build -j
```

Результат: `firmware/rp2040/spi_bringup/build/gb_cart_rp2040.uf2`.
Сохранённый [UF2](../../../releases/rp2040/spi_bringup/gb_cart_rp2040.uf2)
обновлён последней локальной сборкой; метаданные и SHA-256 — в
[манифесте](../../../releases/rp2040/spi_bringup/MANIFEST.md).

## Запуск

Загрузить UF2 через BOOTSEL и открыть USB CDC-порт платы в терминале.
Команды отправляются строками с переводом строки:

| Команда | Действие |
|---|---|
| `version` или `v` | Один запрос версии FPGA, вывод TX/RX и результата |
| `test [N]` | N запросов, по умолчанию 1000; итоговые счётчики и первый ошибочный ответ |
| `help` или `?` | Справка |

Успешный `version` заканчивается строкой
`OK: FPGA protocol 1.0, capabilities=0x0000`.
`test 1000` должен вывести `TEST: total=1000 pass=1000 fail=0 ...` и `PASS`.
Серия выполняется без промежуточного вывода.

Проверку ответа выполняет сама RP2040; отдельной программы автоматической
проверки USB на ПК пока нет. Порядок фиксации результата — в
[аппаратной приёмке](../../../docs/SPI_BRINGUP.md#аппаратная-приёмка).

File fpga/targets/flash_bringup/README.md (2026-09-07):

# Первичная проверка внешней Flash

Конфигурация состоит из:

- `top.v` — последовательность идентификации, стирания, записи и проверки;
- `../../rtl/mx29_bus.v` — низкоуровневые циклы параллельной шины.

Результаты испытаний — в [журнале](../../../docs/TEST_PLAN.md#журнал-результатов),
точный состав проверенной сборки и контрольные суммы — в
[манифесте выпуска](../../../releases/fpga/flash-bringup-pass/MANIFEST.md).

Сейчас проект ссылается на `../../constraints/internal_rom.lpf`, где уже есть
назначения Flash вместе с портами Game Boy. Перед следующей сборкой нужно
выделить назначения Flash в отдельный LPF и сверить их со стендом и схемой.
Это также устранит 54 предупреждения Map об отсутствующих портах Game Boy.

Внимание: `top.v` стирает выбранные секторы и записывает тестовые данные. До
запуска необходимо проверить адреса и ограничения выводов. Эта автономная
сборка начинает тест автоматически и не имеет входа выбора `GAME / PROGRAMMER`:
использовать её следует на отдельном стенде программирования с отключённым
Game Boy. В интегрированном программаторе выбор режима ещё предстоит реализовать.

## Сборка

Из корня репозитория открыть `fpga/diamond/RomEmu.ldf` в Diamond, выбрать
реализацию `flash_bringup` и верхний модуль `top`. Выполнить синтез, Map,
Place & Route и `Export Files -> JEDEC File`, как описано в
[общей инструкции](../../README.md#работа-в-lattice-diamond).
Результат: `fpga/diamond/flash_bringup/RomEmu_flash_bringup.jed`.
Для повторения сохранённого аппаратного опыта используйте JEDEC из выпуска;
результат новой сборки требует собственной проверки.

## Диагностика этапа сбоя мультиметром

Диагностика присутствует в текущем исходнике и выпуске `flash-bringup-pass`;
в сохранённом `flash-bringup-fail` её нет.

После ошибки pin 82 (`test_pass`) остаётся LOW, а pin 83 (`test_fail`)
выдаёт повторяющиеся группы импульсов. Один импульс: около 2 с HIGH и
2 с LOW. После последнего импульса LOW длится около 10 с суммарно.
Мультиметр подключается между pin 83 и GND в режиме измерения постоянного
напряжения. Нужно дождаться длинной паузы и посчитать подъёмы напряжения
в следующей полной группе; подтвердить число по второй группе.

| Импульсов | Место сбоя |
|---|---|
| 1 | ID производителя не равен ожидаемому в тесте `C2` |
| 2 | ID устройства не равен ожидаемому в тесте `A7` или `A8` |
| 3 | Начало одного из стираемых секторов прочитано не как `FF` |
| 4 | Ошибка сравнения одного из 16 шаблонов данных |
| 5 | Опорный адрес `010000` прочитан не как `A5` |
| 6 | Ошибка сравнения одной из 22 адресных проб |
| 7 | Недопустимое состояние тестового автомата |

При успехе pin 82 постоянно HIGH, pin 83 постоянно LOW. Пока тест выполняется,
оба вывода LOW; штатная последовательность занимает около 18 с.
Пауза LOW внутри кода ошибки не означает успех. После FAIL новые команды
Flash не выдаются; группа повторяется до перезапуска питания.

Код определяет проверку, обнаружившую ошибку, но не доказывает физическую
неисправность соответствующей линии. Фактические прочитанные байты и адрес
пока не выдаются. После определения кода можно сузить следующий эксперимент.

## Проверка диагностики

Добавлен тест `fpga/tests/flash_bringup_tb.sv` с моделью команд и памяти,
сценарием PASS, шестью ошибками чтения и недопустимым состоянием.
Проверяются две полные группы каждого кода, стабильность PASS и отсутствие
новых команд памяти после завершения. Временные задержки в симуляции сокращены.
Это функциональная проверка, а не модель электрических параметров MX29LV320E.

Запуск из корня репозитория с установленной Questa Lattice OEM Edition:

```powershell
New-Item -ItemType Directory -Force fpga/tests/build | Out-Null
Set-Location fpga/tests/build
& C:/lscc/diamond/3.14/questasim/win64/vsim.exe -c -do ../flash_bringup.do
```

## Стартовый сброс и проверка netlist

Четыре примитива `FD1S3AX` формируют явный синхронный сброс на первых четырёх
тактах для тестового автомата, контроллера шины и диагностики.
История ошибки начального состояния приведена в журнале испытаний.

Добавлен `fpga/tests/flash_startup_netlist_tb.sv`: используется схема LSE
`top_prim.v` и библиотека Lattice `ovi_machxo2`, а не RTL-модель `initial`.
Подтверждены завершение стартового сброса, начальная задержка и неактивная
шина Flash. Из `fpga/tests/build` после синтеза:

```powershell
& C:/lscc/diamond/3.14/questasim/win64/vsim.exe -c -do ../flash_startup_netlist.do
```

В модели сгенерированной схемы остаются предупреждения о неподключённых
неиспользуемых входах LUT. Функциональные проверки завершились без ошибок.
Симуляция RTL отдельно покрывает всю последовательность теста и коды ошибок.

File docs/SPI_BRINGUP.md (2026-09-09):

# Первый обмен RP2040-Zero ↔ FPGA

Инструкция для [FPGA spi_bringup](../fpga/targets/spi_bringup/README.md) и
[прошивки RP2040](../firmware/rp2040/spi_bringup/README.md).
Текущее состояние реализации и проверок — в [STATUS.md](STATUS.md).

2026-09-07 аппаратный тест **PASS**. [Журнал испытаний](TEST_PLAN.md#журнал-результатов).

## Подключение стенда

Waveshare RP2040-Zero, SPI0. Подключение — по
[схеме KiCad](../hardware/cartridge/cartridge.kicad_sch), U8 и U5.
Используется проводной стенд; разводка PCB не завершена.

Для опыта RP2040-Zero питается от USB, FPGA — от существующего питания стенда.
Соединяется общая земля; выходы 3,3 В двух источников между собой не соединяются.
Сигналы SPI имеют уровень 3,3 В. Game Boy на этом этапе отключён.
Обмен запускается после включения обоих устройств; перед отключением одного
из них обмен останавливается и сигнальные соединения размыкаются.
Питание U8 в основной схеме пока не разведено: приведённая схема питания
стенда не закрывает проектирование питания картриджа.

## Минимальный протокол, версия 1.0

RP2040 — ведущий, FPGA — ведомое устройство. SPI Mode 0 (CPOL=0, CPHA=0),
8 бит, старший бит первым. Начальная частота — 10 кГц. CS# активен низким
уровнем; SCK в покое низкий. Между установкой CS# и первым фронтом SCK,
между последним спадом SCK и снятием CS#, а также между кадрами выдерживается
не менее 20 мкс. CS# остаётся низким на протяжении всего кадра. Перед первым
запросом после конфигурации FPGA выдерживается не менее 1 мс с CS#=1 и SCK=0.

Единственная команда первого этапа — `GET_VERSION = 0x01`.
Кадр содержит ровно 9 байт: команду и 8 нулевых байт для тактирования ответа.

```text
MOSI: 01 00 00 00 00 00 00 00 00
MISO: 00 47 42 46 43 01 00 00 00
         G  B  F  C  major minor capabilities
```

Первый принятый байт игнорируется ведущим. Ответ содержит сигнатуру `GBFC`,
старшую и младшую версии (1 и 0) и 16-битное поле возможностей, младший байт
первым. Значение возможностей `0x0000` означает отсутствие команд памяти.
Оно не сообщает результат теста Flash и не разрешает запись.

FPGA принимает MOSI по нарастающему фронту и меняет MISO по спадающему.
При CS#=1 MISO находится в высокоимпедансном состоянии; начало нового кадра
сбрасывает счётчики и разбор команды. Неизвестная команда возвращает восемь
нулей. Дополнительные байты в том же кадре возвращают нули и не запускают
новые команды. Снятие CS# обрывает неполный кадр без побочных действий.

RP2040 проверяет восемь байт ответа и выводит результат в USB CDC-консоль.
CRC на фиксированном ответе не используется. Команды памяти реализованы
в отдельном [протоколе программатора 3.0](PROGRAMMER_PROTOCOL.md).

## Аппаратная приёмка

1. Использовать готовые выпуски [FPGA spi_bringup](../releases/fpga/spi_bringup/MANIFEST.md)
   и [RP2040 spi_bringup](../releases/rp2040/spi_bringup/MANIFEST.md).
2. Сверить монтаж и назначения выводов в отчёте Diamond по
   [процедуре LPF](TEST_PLAN.md#сверка-lpf).
3. Загрузить обе сборки, включить стенд и выполнить `version` в USB CDC-консоли.
4. Выполнить `test 1000`: все ответы должны пройти проверку.
5. Сохранить журнал USB, ревизии исходников, JEDEC и UF2 с контрольными суммами;
   результат записать в [журнал испытаний](TEST_PLAN.md#журнал-результатов).

Чтение и запись Flash реализованы и проверены в отдельном
[блочном программаторе](PROGRAMMER.md).

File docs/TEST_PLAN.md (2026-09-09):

# План испытаний

## Уровни подтверждения

- **Проверено на аппаратуре:** результат наблюдался на указанном стенде.
- **Проверено в симуляции:** пройден описанный тест RTL или netlist; аппаратный
  результат этим не подтверждается.
- **Реализовано:** исходник или схема существует, но обязательный тест не
  пройден.
- **Запланировано:** зафиксирован только замысел.

Статус нельзя повышать до «проверено» без фиксации конфигурации, ревизии
артефакта, испытательного стенда и наблюдаемого результата.

## Журнал результатов

### 2026-09-09 — LSDj / MBC5: программные проверки — PASS

Добавлена конфигурация `game_mbc5` для ROM 1 МиБ и RAM 128 КиБ.
Icarus Verilog: 512 значений регистра ROM с зеркалированием на 64 банка,
границы ROM, два полных прохода записи/чтения 128 КиБ RAM, запрет RAM,
CS#, сброс, игнорируемые записи, направление данных — PASS.
В модели проверены precharge, CE#/WE# и setup данных F-RAM.
[Команды и параметры модели](../fpga/targets/game_mbc5/README.md#проверка-на-mac).

PROGRAMMER: F-RAM отключена при старте и SPI — PASS; регрессия блочного
RTL v3 на SPI 4 МГц — PASS. 11 host-тестов и тест C-кода RP2040 — PASS.
На модели с локальным `lsdj9_4_2.gb` пройдены два полных чтения 4 МиБ,
стирание, запись и побайтовое сравнение 1 МиБ для Top/Bottom Boot.
Данные за пределами ROM сохранены. Это программный тест, аппаратные
файлы дампов и измерения скорости LSDj не получены.
Исправлено подключение A10 F-RAM в схеме KiCad. Свежая сетка соединений:
66 назначений GAME, 40 назначений PROGRAMMER и все выводы F-RAM — PASS.
Новые GAME/PROGRAMMER ещё не собраны в Diamond и не проверены на стенде.

### 2026-09-06 — повторный тест внешней Flash: FAIL

- Стенд: Flash-память с контактами, выведенными на гребёнку.
- С новой прошивкой зафиксированы pin 83 — HIGH, pin 82 — LOW.
  Результат: `test_fail=1`, `test_pass=0`, то есть **FAIL**.
- Обновлённые JEDEC и отчёты сохранены в
  [выпуске](../releases/fpga/flash-bringup-fail/MANIFEST.md).
- Добавлена диагностика в текущий исходник: pin 83 выдаёт код этапа группой
  из 1–7 медленных импульсов, pin 82 остаётся LOW при ошибке.
  [Таблица кодов и считывание мультиметром](../fpga/targets/flash_bringup/README.md#диагностика-этапа-сбоя-мультиметром).
- Симуляция диагностики: все восемь сценариев PASS/FAIL прошли в Questa 2024.2;
  диагностический JEDEC собран, TRACE и DRC Bitgen пройдены.
- На аппаратуре считаны семь импульсов HIGH с длинной паузой LOW: код 7.

### 2026-09-06 — исправление стартового сброса: PASS

- Схема после синтеза воспроизвела причину кода 7: старт `state=0xFF`, затем
  `ST_FAIL`. В LSE были предупреждения об игнорировании значений из `initial`.
- Добавлена цепочка из четырёх примитивов `FD1S3AX`, удерживающая оба автомата
  в явном синхронном сбросе при старте. `mx29_bus` получил вход `reset`.
- Все восемь RTL-сценариев прошли; отдельная симуляция схемы после синтеза
  подтвердила корректный старт с неактивной шиной Flash.
- На стенде после новой прошивки зафиксированы **pin 82 HIGH, pin 83 LOW — PASS**.
  Пройдены ID, проверка начал стёртых секторов, 16 шаблонов данных,
  опорный адрес и 22 адресные пробы. Полное покрытие 4 МБ этим не подтверждается.
- Оба успешных запуска выполнены со сборкой от 23:23:22.
  JEDEC и контрольные суммы — в
  [flash-bringup-pass](../releases/fpga/flash-bringup-pass/MANIFEST.md).
- После полного выключения и включения питания PASS повторился.
  Зафиксированы два успешных запуска: после прошивки и после одного цикла
  выключения/включения. Отдельный выпуск с исходниками, отчётами и SHA-256 создан.

### 2026-09-08 — game_rom: аппаратная проверка — PASS

Стенд: Game Boy → преобразователи уровней → FPGA → внешняя Flash,
режим `game_rom`, ROM ONLY 32 КиБ. Игра загружается и работает стабильно —
**PASS**. Проверенная сборка: [RomEmu_game_rom.jed](../releases/fpga/game_rom/RomEmu_game_rom.jed),
отчёты Diamond сохранены в [releases/fpga/game_rom](../releases/fpga/game_rom/).

### 2026-09-08 — game_rom: RTL-проверка

Добавлен асинхронный ROM ONLY 32 КиБ из внешней Flash. Выполнены два
прогона Icarus Verilog: со случайным содержимым и с записанным
`flash-test-20260907-232422/rom.gb` — **PASS**, по 33 793 чтения.
Проверены все адреса ROM, освобождение шины в `8000–FFFF`, границы,
смена адреса при активном RD#, отдельные циклы чтения и изоляция записей CPU.
WE# Flash остаётся HIGH. Модель включает 70 нс доступа Flash и 10 нс
преобразователя данных; post-route задержки FPGA не моделировались.
Проверены 60 уникальных назначений выводов LPF, покрытие портов и пути LDF.
Сборка Diamond и аппаратный запуск ещё не выполнены.
[Конфигурация и инструкция](../fpga/targets/game_rom/README.md).

### 2026-09-07 — SPI: симуляция и сборка FPGA

Перенесено из README конфигурации; при актуализации документации тесты заново
не запускались. RTL и netlist — PASS; Map — без ошибок и предупреждений,
39/640 SLICE; timing setup/hold — 0 ошибок на 2,08 МГц.
Предупреждения LSE относятся к постоянному биту ответа и отсутствию
генерируемого LPF (Map получает отдельный LPF проекта); предупреждения
netlist-симуляции — к незадействованным входам примитивов.
Команды воспроизведения и охват тестов — в
[README конфигурации](../fpga/targets/spi_bringup/README.md#проверка).
Аппаратный результат зафиксирован следующей записью.

### 2026-09-07 — аппаратный SPI bring-up: PASS

Выполнены `version` и `test 1000` на стенде RP2040-Zero ↔ FPGA
с конфигурациями `spi_bringup` — **PASS**:

```text
TX: 01 00 00 00 00 00 00 00 00
RX: 00 47 42 46 43 01 00 00 00
OK: FPGA protocol 1.0, capabilities=0x0000

TEST: total=1000 pass=1000 fail=0 elapsed=8500 ms
PASS
```

Проверены ответ версии 1.0 и 1000 обменов через USB CDC / SPI — **PASS**, ошибок нет.
Последняя локальная сборка RP2040 сохранена в [выпуске с манифестом](../releases/rp2040/spi_bringup/MANIFEST.md).
Рабочий FPGA JEDEC и отчёты сохранены в
[выпуске spi_bringup с манифестом и SHA-256](../releases/fpga/spi_bringup/MANIFEST.md).
Повторный тест после выключения/включения питания пройден — **PASS**.
Команды памяти и полный тракт работы с Flash этим тестом не проверялись.

### 2026-09-07 — подготовка чтения Flash до ПК

Добавлена команда `check-bringup`: чтение 16 шаблонов данных, опорного байта
и 22 адресных проб, оставленных успешным `flash_bringup`, через `programmer`.
Выполнены 7 host-тестов — PASS. Проверены обмен через модель USB-моста,
CRC и последовательность запросов с переходом через 255, два прохода по
39 адресам, остановка при несовпадении и отклонение нулевого числа проходов.
Проверено отсутствие ARM и команд изменения Flash в сценарии чтения.
RTL и прошивка RP2040 не изменены; повторная RTL-симуляция не выполнялась.
На момент подготовки JEDEC, timing/netlist и аппаратное чтение по полному
тракту ещё не проверены; последующие результаты приведены ниже.
[Порядок стенда](PROGRAMMER.md).

### 2026-09-07 — блочный программатор v3

Реализованы блоки до 1 КиБ для чтения и записи, бинарный USB и SPI 4 МГц.
Команда `check-bringup` удалена; текущая процедура — полный дамп, запись ROM
и повторный полный дамп с побайтовым сравнением.
Выполнены 10 host-тестов и тест фактического C-кода RP2040 с моделью SPI — PASS.
Проверены бинарные данные, частичные USB-чтения, CRC, границы, хвост блока,
остановка без повтора, проверка стирания и 4096 запросов полного дампа.
RTL блочного контроллера пройден при SPI 4 МГц и трёх частотах FPGA
(около 42,55, 53,19 и 64 МГц), с моделью задержек Flash 70 нс.
Проверены блоки чтения/записи, ID, стирание, CRC, длины, LOCK, sequence,
кадр во время busy, Q5 и тайм-аут. Регрессионный RTL-тест v2 также пройден.
UF2 v3 собран с `-Wall -Wextra -Werror`; метаданные проверены picotool.
[Выпуск и исходники](../releases/rp2040/programmer-v3/MANIFEST.md).
На момент подготовки Diamond Map/EBR/timing/JEDEC, аппаратный полный дамп,
запись и скорость ещё не проверены; последующие результаты приведены ниже. [Порядок стенда](PROGRAMMER.md).

### 2026-09-07 — programmer v3: нарушение setup после Place & Route

Размещение и трассировка завершены: 518/640 SLICE, 2/7 EBR, все соединения
разведены. В отчёте TRACE зафиксированы 4096 setup errors, hold errors — 0. Критический путь:
`protocol/header__i8` → `protocol/incoming_1335`, 24,542 нс, 23 уровня логики,
slack −6,093 нс. Расчётная максимальная частота — 40,177 МГц.
Отчёт использует constraint 53,200001 МГц; соответствие исходному LPF
с требованием 64 МГц пока не подтверждено.

В рабочем RTL расчёт границ кадра и проверки CRC, sequence и диапазона
разделены регистрами; адрес записи входного буфера ограничен 10 битами.
Формат v3 и совместимость UF2 сохранены. RTL-тесты исправления пройдены
при SPI 4 МГц и частотах FPGA около 42,55/53,19/64 МГц, включая кадры
с недостающим и лишним битом CRC. Повторное размещение и TRACE
исправленного RTL требуются до аппаратного испытания.

### 2026-09-07 — полный цикл Flash на Mac: PASS

Выполнен цикл через `programmer` v3: полный дамп → запись ROM → повторный
полный дамп → побайтовое сравнение. Стенд: Mac, RP2040-Zero, FPGA,
MX29LV320E **C2/A7, Top Boot**; USB-порт `/dev/cu.usbmodem101`.
[Журнал консоли и файлы испытания](../flash-test-20260907-232422/log.txt).

- Сохранены `before.bin` и `after.bin`, каждый по **4 194 304 байта**.
- Стёрт сектор `000000..00FFFF` (64 КиБ); выполнена проверка всех его байтов.
- Записан `ttr.gb` с адреса 0, **32 768 байт**; копия сохранена как `rom.gb`.
  Встроенная проверка записи завершена: `Result: SUCCESS`.
- Повторный полный дамп выполнен за **27,553 с** по `time`;
  итоговая скорость чтения утилиты — **162,3 КиБ/с**. Для первого дампа —
  162,2 КиБ/с; отдельное полное время первого чтения не записано.
- Все 32 768 байт ROM побайтово совпадают с началом `after.bin` — **PASS**.

При проверке сохранённых файлов подтверждены SHA-256 из `before.sha256`
и `after.sha256`, размеры обоих дампов и совпадение `ttr.gb` с `rom.gb`.
Дополнительно проверено: `after.bin[008000..00FFFF]` заполнен FF;
диапазон `010000..3FFFFF` побайтово совпадает в обоих дампах.
Таким образом, изменения ограничены стёртым сектором, а записанный ROM
полностью совпадает с повторно считанными данными.

Время записи отдельно не измерено. Рабочая FPGA-сборка этого испытания
сохранена в [выпуске programmer-v3 с манифестом и SHA-256](../releases/fpga/programmer-v3/MANIFEST.md).
Результат повторного TRACE приведён следующей записью.

### 2026-09-07 — programmer v3: повторный TRACE пройден

В [сохранённом TRACE](../releases/fpga/programmer-v3/RomEmu_programmer.twr)
подтверждены **0 setup errors, 0 hold errors**, cumulative negative slack — 0.
Применённая частота — **53,200001 МГц**, расчётная максимальная — **58,197 МГц**.
Критический путь после исправления: 16,835 нс, 8 уровней логики;
запас setup **+1,614 нс**, минимальный запас hold **+0,287 нс**.

В [Map report](../releases/fpga/programmer-v3/RomEmu_programmer.mrp)
зафиксировано предупреждение: значение FREQUENCY 64 МГц недопустимо для OSCH;
оно заменено на NOM_FREQ 53,20 МГц. Это объясняет частоту в TRACE.
Таким образом, timing пройден на номинальных 53,2 МГц; проверка с запасом
до 64 МГц этим отчётом не выполнена. JEDEC и отчёты сохранены в
[выпуске FPGA с манифестом](../releases/fpga/programmer-v3/MANIFEST.md).

## Сверка LPF

Сверка выполняется для каждой конфигурации отдельно с учётом
[приоритета источников](README.md#приоритет-источников):

1. После синтеза открыть в Diamond `Spreadsheet View -> Port Assignments`.
   Diamond формирует полный список портов верхнего уровня автоматически;
   поддерживать отдельный список вручную не нужно.
2. Убедиться, что для каждого аппаратного порта в этой таблице заданы правильный
   вывод FPGA и электрический стандарт. В LPF им соответствуют записи
   `LOCATE COMP ... SITE ...` и `IOBUF`.
3. В схеме `hardware/cartridge/cartridge.kicad_sch` найти FPGA `U5` и для
   каждого порта сопоставить имя цепи и номер вывода с `SITE` в LPF. Шины нужно
   проверять поразрядно: например, `gb_a[0]` нельзя считать проверенным по
   совпадению только имени шины `gb_a`.
4. Проверить, что выбранные в Diamond устройство и корпус совпадают со схемой:
   `LCMXO2-1200HC-4TG100C`.
5. Убедиться, что в LPF нет ограничений для отсутствующих портов, а среди
   аппаратных портов `top` нет портов без назначения вывода. Предупреждения
   Diamond о выводах и стандартах ввода-вывода должны быть разобраны до
   программирования устройства.
6. После сборки сохранить отчёт о назначении выводов и сравнить его с LPF;
   результат сверки зафиксировать вместе с именем конфигурации и исходным
   коммитом.

Изменять схему только для устранения расхождения с LPF нельзя. Если найдено
расхождение, сначала нужно установить ожидаемое соединение по правилам
приоритета источников, а затем исправить зависимый артефакт.

## Проверка FPGA

Для каждой конфигурации сборки:

1. выполнить синтез;
2. выполнить описанную выше сверку LPF;
3. выполнить отображение логики, размещение, трассировку и генерацию потока
   конфигурации;
4. сохранить количество ошибок и предупреждений и отчёт временного анализа;
5. для асинхронных шин проверить заданные максимальные комбинационные задержки,
   а не только общий результат временного анализа.

Симуляция контроллера Flash должна покрывать чтение, последовательности команд,
тайм-аут, возврат в обычный режим чтения и невозможность одновременного
управления шиной несколькими устройствами.

## Проверка аппаратной части

До подачи питания:

- выполнить ERC схемы и DRC PCB;
- проверить сопротивление между питанием и землёй и целостность собранных цепей;
- проверить неактивные состояния Flash `CE#/OE#/WE#`, F-RAM `CE#/OE#/WE#` и
  `OE/DIR` преобразователей уровней;
- убедиться, что USB и Game Boy не могут питать друг друга обратным током.

## Последовательность первичной проверки

Этапы интеграции и критерии приёмки перечислены в [ROADMAP.md](ROADMAP.md).
Отдельная процедура первого обмена — в [SPI_BRINGUP.md](SPI_BRINGUP.md#аппаратная-приёмка).

## Данные выпуска

Требования к составу выпуска и проверке его целостности — в
[releases/README.md](../releases/README.md).

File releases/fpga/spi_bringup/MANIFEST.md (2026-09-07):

# FPGA spi_bringup — проверенный выпуск 2026-09-07

Проверены ответ версии 1.0, capabilities `0x0000` и 1000/1000 обменов — **PASS**.
Подробности испытания — в [журнале](../../../docs/TEST_PLAN.md#журнал-результатов).

## Сборка и совместимость

- FPGA: `LCMXO2-1200HC-4TG100C`, верхний модуль `top`.
- Конфигурация Diamond: `spi_bringup`.
- Инструменты: Lattice Diamond 3.14.0.75.2.
- Время Bitgen по отчёту: 2026-09-07 19:50:18; часовой пояс не указан.
- Точный исходный коммит сборки в отчётах не зафиксирован.

Совместим с [RP2040 spi_bringup](../../rp2040/spi_bringup/MANIFEST.md);
управление через USB CDC-команды `version` и `test 1000`.
Команды Flash не поддерживаются.

## Результаты Diamond

- Map: 43/640 SLICE, 0 ошибок, 0 предупреждений.
- TRACE: 0 setup / 0 hold ошибок при constraint 2,08 МГц;
  минимальный setup slack +472,723 нс, hold +0,304 нс.
- Place & Route: все соединения разведены, 0 ошибок.
- Bitgen DRC: 0 ошибок, 0 предупреждений.

## Файлы

| Файл | Назначение |
| --- | --- |
| [RomEmu_spi_bringup.jed](RomEmu_spi_bringup.jed) | Готовая прошивка FPGA |
| [RomEmu_spi_bringup.bgn](RomEmu_spi_bringup.bgn) | Bitgen и DRC |
| [RomEmu_spi_bringup.mrp](RomEmu_spi_bringup.mrp) | Map, ресурсы и предупреждения |
| [RomEmu_spi_bringup.par](RomEmu_spi_bringup.par) | Place & Route |
| [RomEmu_spi_bringup.twr](RomEmu_spi_bringup.twr) | TRACE: setup и hold |
| [RomEmu_spi_bringup.pad](RomEmu_spi_bringup.pad) | Назначения выводов |
| [RomEmu_spi_bringup.prf](RomEmu_spi_bringup.prf) | Ограничения, применённые Diamond |

SHA-256 всех файлов выпуска, включая этот манифест, сохранены в
[SHA256SUMS.txt](SHA256SUMS.txt). Проверка на Mac из корня проекта:

```sh
(cd releases/fpga/spi_bringup && shasum -a 256 -c SHA256SUMS.txt)
```

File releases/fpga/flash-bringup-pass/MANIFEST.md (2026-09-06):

# Flash bring-up — проверенный выпуск 2026-09-06

**Результат на аппаратуре: PASS**, повторён после полного выключения и включения
питания. Подтверждено, что оба запуска выполнены с этой сборкой от 23:23:22.

- FPGA: `LCMXO2-1200HC-4TG100C`, Flash: MX29LV320E.
- Реализация Diamond: `flash_bringup`, верхний модуль `top`.
- Инструменты: Lattice Diamond 3.14.0.75.2, LSE; Questa Lattice OEM 2024.2.
- Стенд: Flash-память с контактами, выведенными на гребёнку.
- Индикация PASS: **pin 82 HIGH (`test_pass`), pin 83 LOW (`test_fail`)**.

## Прошивка и контрольные суммы

Готовый файл: [RomEmu_flash_bringup.jed](RomEmu_flash_bringup.jed).

SHA-256:
`2a8d711c5d1193ff089ecf9b793f715498bb9f604ceef1adfe8c8a68ba0600c9`.

Контрольные суммы всех файлов выпуска, включая исходники и этот манифест,
сохранены в [SHA256SUMS.txt](SHA256SUMS.txt). Сам файл сумм в список не включён.
Время генерации JEDEC по Bitgen: 2026-09-06 23:23:22; часовой пояс в отчёте
не указан. Это последняя аппаратно проверенная сборка, заменяющая в документации
предварительный диагностический JEDEC с SHA-256 `b05a04eb…`.

## Ревизия исходников

Базовый коммит: `faedb6743bfa1991f3b46a2a2fb833db2ea6c05f`.
На момент выпуска изменения `top.v` и `mx29_bus.v`, а также новые тесты ещё
не закоммичены. Поэтому один базовый коммит не воспроизводит этот выпуск.
Точное содержимое текущих исходников, проекта и ограничений сохранено в
`source/` с исходной структурой каталогов и SHA-256 каждого файла.

В снимке сохранён общий `internal_rom.lpf`, использованный при сборке,
без очистки ограничений Game Boy. Исходная реализация `v1_0` и её `top.v`
также включены для целостности проекта Diamond.

Для повторной сборки открыть `source/fpga/diamond/RomEmu.ldf`, выбрать
`flash_bringup`, выполнить Synthesis, Map, Place & Route и экспорт JEDEC.
Рабочие результаты появятся в `source/fpga/diamond/flash_bringup/`.
Файл `.xcf` сохранён как настройка исходного стенда: при программировании
следует проверить выбранный кабель и указать JEDEC именно из этого выпуска.
Повторная сборка может иметь другую контрольную сумму из-за метаданных и
решений размещения; для повторения аппаратного опыта использовать сохранённый JEDEC.

## Исправление и охват теста

Причина предыдущего FAIL с кодом 7 воспроизведена на схеме после синтеза:
начальные значения из `initial` были проигнорированы, `state` начинался с
`0xFF` и переходил в `ST_FAIL` до проверки Flash.

Добавлены четыре примитива `FD1S3AX`, формирующие явный стартовый сброс
тестового автомата, контроллера шины и диагностики. Сохранены медленные
импульсные коды ошибок на pin 83.

PASS означает прохождение предусмотренной последовательности:

- ID производителя `C2`, ID устройства `A7` или `A8`;
- стирание семи выбранных секторов и чтение `FF` по адресу начала каждого;
- запись и чтение 16 шаблонов данных;
- проверка опорного адреса `010000` со значением `A5`;
- запись и чтение 22 адресных проб.

Это не полная проверка всех 4 МБ. USB/SPI, загрузка Game Boy из Flash и F-RAM
в этом испытании не проверялись. Один повтор после выключения питания подтверждён;
длительные циклические испытания ещё не проводились.

Тест автоматически стирает и записывает данные. Он предназначен для отдельного
стенда программирования: затрагиваются секторы с адресами `010000`, `020000`,
`030000`, `050000`, `090000`, `110000`, `210000`.

## Отчёты и проверки

| Отчёт | Результат |
|---|---|
| `synthesis.log` | LSE: стартовый сброс включён, предупреждений об игнорировании начальных значений нет |
| `.mrp` | 313/640 SLICE (49%), 623/1280 LUT4 (49%); 0 ошибок, 54 предупреждения |
| `.par` | Размещение и трассировка завершены |
| `.twr` | 0 ошибок setup/hold при 2,08 МГц; покрытие 99,70% |
| `.bgn` | DRC: 0 ошибок, 0 предупреждений; JEDEC создан |
| `.pad` | Вывод 82 — `test_pass`, 83 — `test_fail` |
| `.prf` | Сохранены итоговые ограничения реализации |

54 предупреждения Map относятся к отсутствующим в этой конфигурации портам
Game Boy из общего LPF. Полная сверка разводки со схемой и отдельная проверка
внешних временных параметров Flash этими отчётами не заменяются.

В Questa пройдены восемь функциональных сценариев и отдельная проверка
старта схемы после синтеза с моделями Lattice. Тесты включены в `source/fpga/tests/`.

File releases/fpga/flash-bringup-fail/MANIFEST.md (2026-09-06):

# Базовая конфигурация проверки внешней Flash

2026-09-06 проведена проверка внешней Flash на аппаратуре. JEDEC
и отчёты этой сборки сохранены в данном каталоге. Первоначальная оценка успеха исправлена:
тест провален. После исправления пинаута и повторной прошивки результат — **FAIL**.

**Реализация:** `flash_bringup`, верхний модуль `top`

**Микросхема FPGA:** `LCMXO2-1200HC-4TG100C`

**Flash:** MX29LV320E

**Инструмент:** Lattice Diamond 3.14.0.75.2

**Базовый коммит:**
`d909465968abc2fc8bafdef35926c2295e65aebd` (`Tested Flash memory, working`)

Текущая сборка использует рабочее дерево поверх этого коммита: поменяны
местами назначения `test_fail/test_pass` в `fpga/constraints/internal_rom.lpf`,
обновлены JEDEC и отчёты выпуска. Эти изменения пока не закоммичены;
`d909465` не является точной ревизией текущей сборки. После фиксации изменений
нужно записать новый коммит. Отчёт `.pad` также добавлен после базового коммита.

**Время сборки по отчётам Diamond:** 2026-09-06, Map 22:34:53,
TRACE 22:35:23, Bitgen 22:35:25. Часовой пояс в отчётах не указан.

## Исходные файлы

- `fpga/targets/flash_bringup/top.v` — автономная тестовая последовательность.
- `fpga/rtl/mx29_bus.v` — низкоуровневые циклы Flash.
- `fpga/diamond/RomEmu.ldf` — проект с реализацией `flash_bringup`.
- `fpga/constraints/internal_rom.lpf` — общий LPF с назначениями Game Boy
  и Flash, с исправленным пинаутом в рабочем дереве.

Отдельного исходного `flash_bringup.lpf` пока нет. В командной строке Map
также указан рабочий `fpga/diamond/flash_bringup/RomEmu_flash_bringup.lpf`;
его текущая локальная копия содержит только закомментированные строки.
При разделении LPF исходный выпуск и его отчёты нужно сохранить без изменений.

## Файлы

| Файл | SHA-256 |
|---|---|
| `RomEmu_flash_bringup.jed` | `bd3aea9084ed260fd7594eeb0e50f9c02bae8abe2c3cb2d7f76303f7851ae5d3` |
| `RomEmu_flash_bringup.twr` | `010412d6b2b138169eee97c8d5548f3952ec0aada21c5bf38a902ca05501b285` |
| `RomEmu_flash_bringup.mrp` | `8115de3fefad1810eb816a68906209c83d0687234a726ec6b9a3381ef590a89f` |
| `RomEmu_flash_bringup.bgn` | `e483d82426edad0c9f529f0c86d184a0a157329cfae77d59c91c83b13199d953` |
| `RomEmu_flash_bringup.pad` | `34dfae20c204a545c680b1c91a2a4b043a5f5e820bcbda7458fa267164b50ad7` |

## Результаты проверки отчётов

- Map: 0 ошибок, 54 предупреждения из-за ограничений отсутствующих портов
  Game Boy в общем `internal_rom.lpf`; эти ограничения отключены инструментом.
- Ресурсы: 559 из 640 SLICE (87%), 1099 из 1280 LUT4 (86%). Это следует
  учитывать при интеграции SPI и интерфейса Game Boy.
- TRACE: 0 ошибок setup и hold для ограничения `clk` 2,08 МГц;
  покрытие ограничениями — 99,82%. Отчёт не является отдельной проверкой
  внешних временных параметров Flash или шины Game Boy.
- Bitgen: DRC — 0 ошибок и 0 предупреждений; JEDEC создан.
- PAD: отчёт от 2026-09-06 22:35:19 для `LCMXO2-1200HC`, TQFP100,
  скоростная градация 4. Назначения индикаторов совпадают с обновлённым LPF:
  83 — `test_fail`, 82 — `test_pass`.
  Сверка с физическим стендом и схемой ещё не зафиксирована.

## Стенд и наблюдаемый результат

Использована Flash-память с контактами, выведенными на гребёнку.
LPF исправлен согласно исходному замыслу: `test_fail` — pin 83,
`test_pass` — pin 82. С новой прошивкой зафиксированы pin 83 — HIGH,
pin 82 — LOW: **тест провален**.

По `fpga/constraints/internal_rom.lpf` и сохранённому в выпуске отчёту
`RomEmu_flash_bringup.pad` вывод 83 — `test_fail`,
вывод 82 — `test_pass`. В `top.v` состояние `ST_FAIL` устанавливает
`test_fail=1`, `test_pass=0`; для `ST_PASS` уровни обратные.

Причина перехода в `ST_FAIL` пока неизвестна: итоговые два сигнала не
показывают, на какой операции произошёл сбой. Следующий шаг — добавить
диагностику этапа и данных ошибки, затем повторить испытание.

## Что ещё нужно добавить

1. Результат сверки сохранённого `.pad` со стендом и схемой. Для полноты
   архива также полезен итоговый `.prf` из `fpga/diamond/flash_bringup/`.
2. Подробности стенда: точная маркировка Flash, соединения с FPGA, питание
   и способ наблюдения уровней на выводах 82/83.
3. Этап и причину сбоя, фактически выполненные операции, проверенные адреса и число повторов,
   включая повтор после выключения питания.

В исходнике предусмотрены идентификация, стирание, запись и проверка тестовых
данных. Подробности фактического испытания пока не записаны. Полный тракт
USB/SPI, проверка всех 4 МБ и запуск Game Boy из Flash остаются следующими этапами.

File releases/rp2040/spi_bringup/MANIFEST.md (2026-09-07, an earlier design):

# RP2040 SPI bring-up — 2026-09-07

## Артефакт

- Файл: [gb_cart_rp2040.uf2](gb_cart_rp2040.uf2), 80896 байт.
- SHA-256: `a2cba0aedb337bc30e8ba97e367cef52164f00ab2bb95addc02bc0a7c4e27a28`.
- Скопирован без пересборки из `firmware/rp2040/spi_bringup/build/gb_cart_rp2040.uf2`.
- Время изменения исходного файла: 2026-09-07 20:24:47 (Asia/Nicosia).
- Конфигурация: `spi_bringup`, Waveshare RP2040-Zero, протокол FPGA 1.0.
- Текущая ревизия репозитория при сохранении: `4c0a7b8dd871d8f4c41193bbbc22fd10b25a9fbf`;
  рабочее дерево до обновления документации и выпуска было чистым.
  Ревизия непосредственно в момент сборки не записана в артефакте.

## Инструменты

По сохранённым файлам каталога сборки:

- Pico SDK 2.3.1 (`generated/pico_base/pico/version.h`).
- ARM GCC 9.2.1 (`CMakeFiles/*/CMakeCCompiler.cmake`).
- Release, `PICO_BOARD=waveshare_rp2040_zero` (`CMakeCache.txt`).
- Путь SDK при сборке: `/Users/kkk/pico-sdk`.

Точные коммиты SDK/TinyUSB и версия picotool для этой сборки не зафиксированы.
[Инструкция сборки и запуска](../../../firmware/rp2040/spi_bringup/README.md).

## Аппаратный результат

Выполнены `version` и `test 1000` на стенде RP2040-Zero ↔ FPGA `spi_bringup`
— **PASS**, 2026-09-07:

```text
TX: 01 00 00 00 00 00 00 00 00
RX: 00 47 42 46 43 01 00 00 00
OK: FPGA protocol 1.0, capabilities=0x0000

TEST: total=1000 pass=1000 fail=0 elapsed=8500 ms
PASS
```

Проверены ответ версии и серия из 1000 запросов — **PASS**, ошибок нет.
Хеши загруженных при испытании UF2 и JEDEC не зафиксированы; соответствие
испытанных байтов этому UF2 отдельно не сверялось. JEDEC в этот выпуск не входит.
Повторный тест после выключения/включения питания пройден — **PASS**.
Чтение, стирание и запись Flash не входят в протокол 1.0 и этим тестом не проверены.

[Журнал испытаний](../../../docs/TEST_PLAN.md#журнал-результатов).

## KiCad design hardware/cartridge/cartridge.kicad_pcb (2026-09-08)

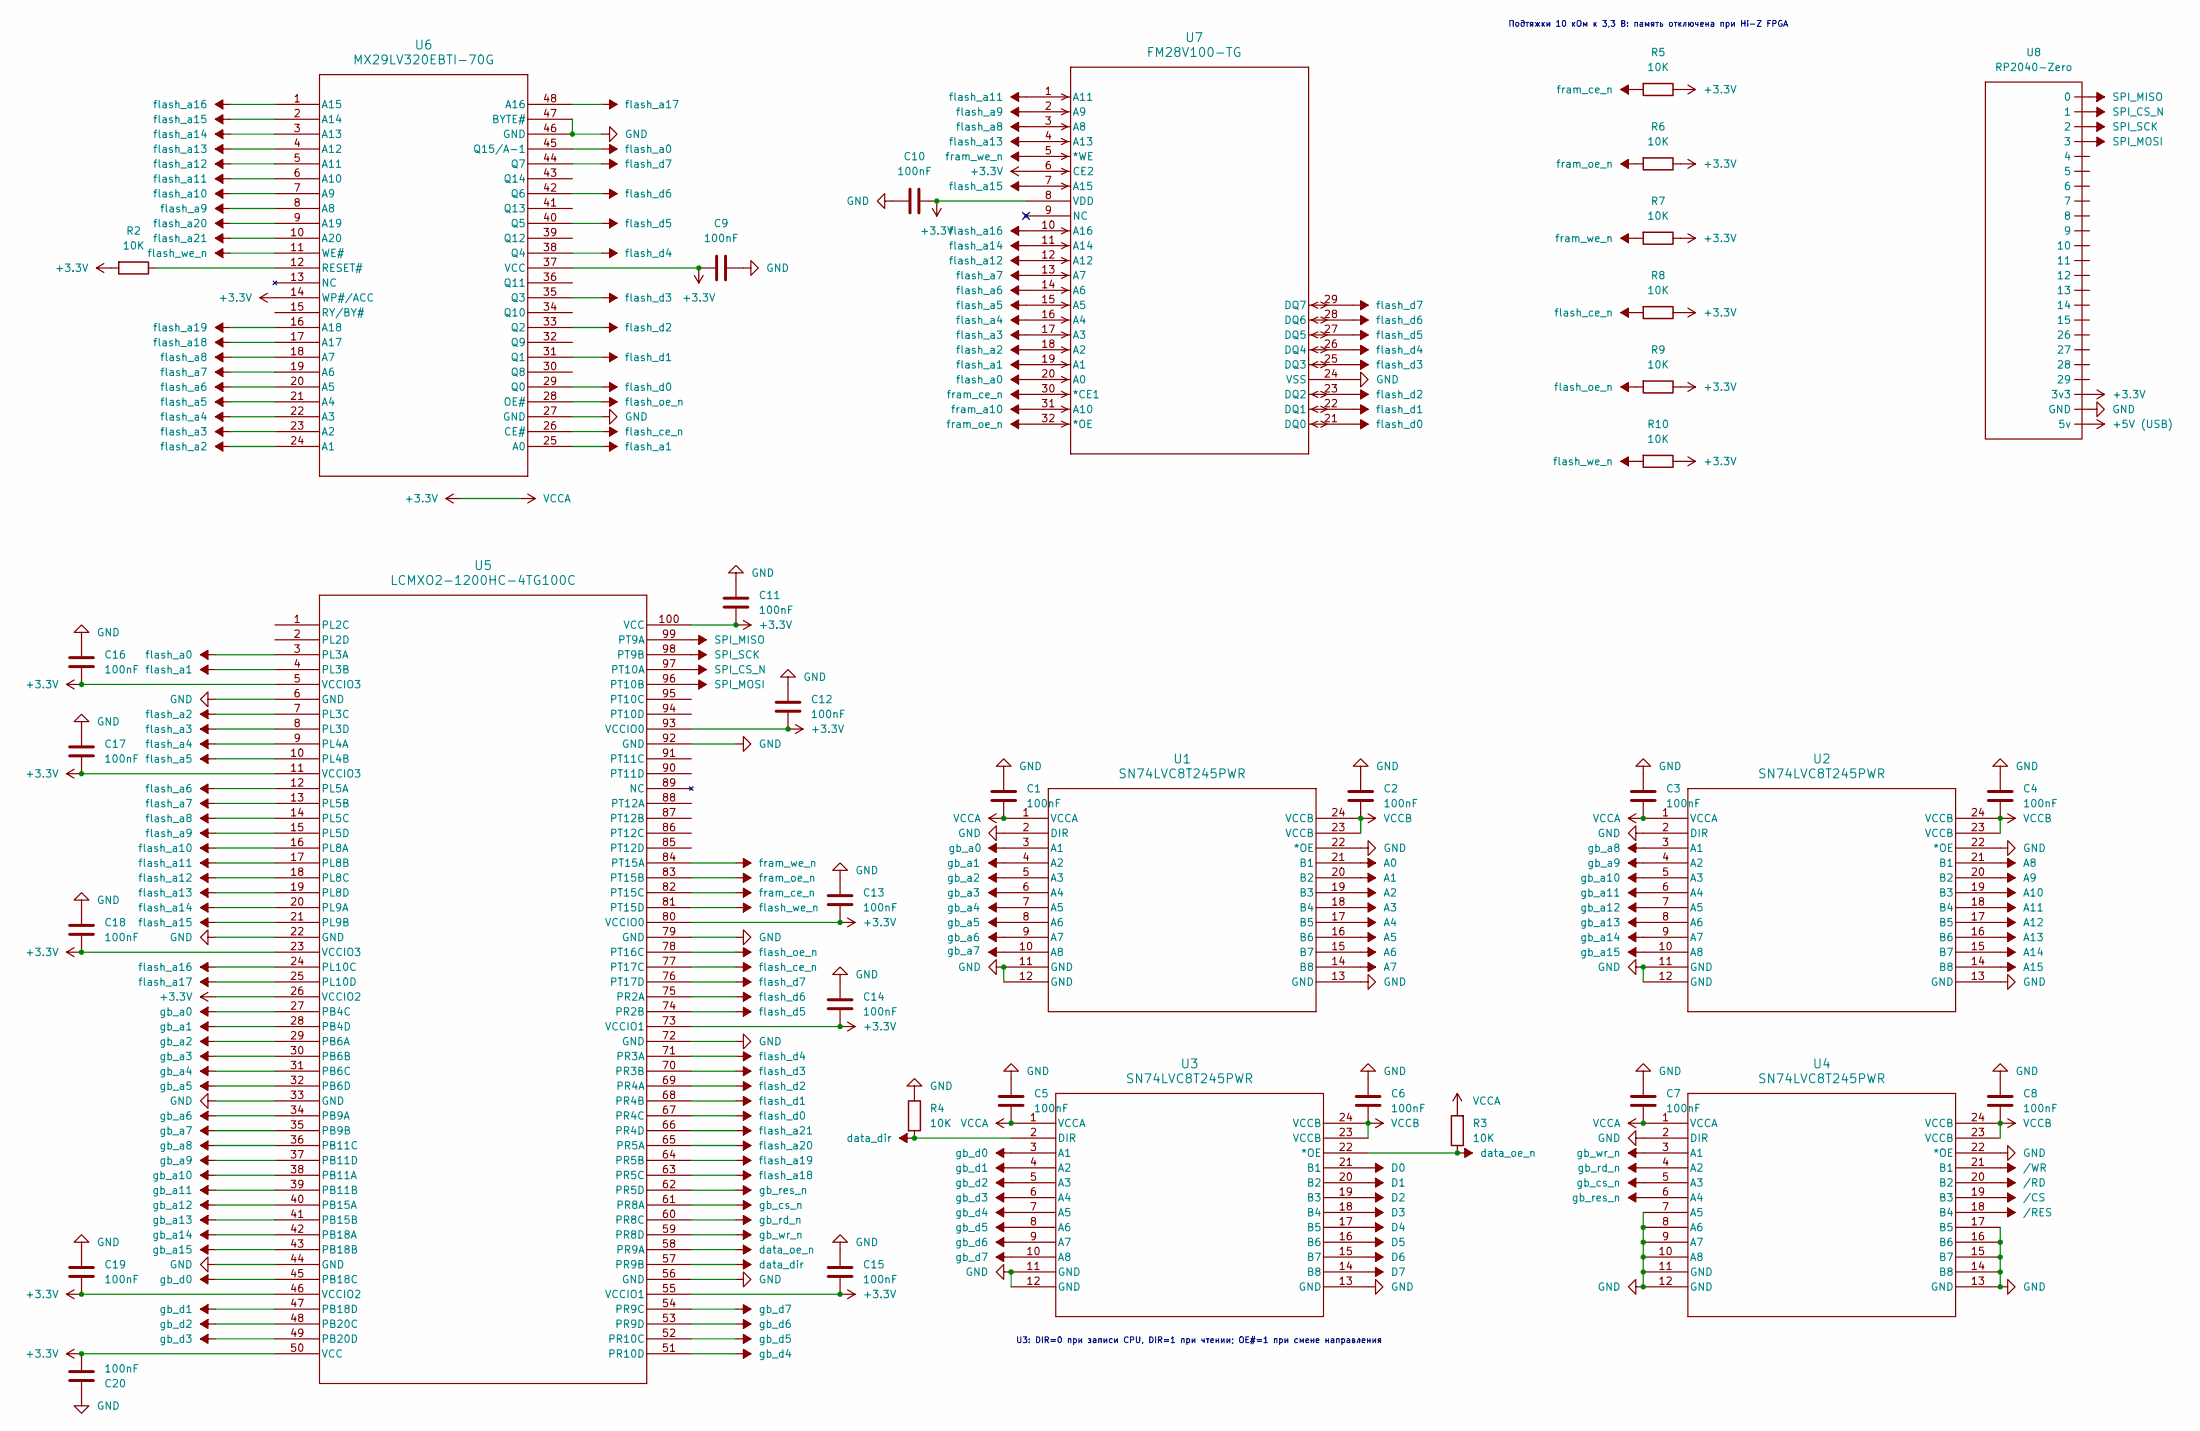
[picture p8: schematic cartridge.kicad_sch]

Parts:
C1, C2, C3, C4, C5, C6, C7, C8, C9, C10, C11, C12, C13, C14, C15, C16, C17, C18, C19, C20: 100nF; C_0603_1608Metric_Pad1.08x0.95mm_HandSolder
R2, R3, R4, R5, R6, R7, R8, R9, R10: 10K; R_0603_1608Metric_Pad0.98x0.95mm_HandSolder
U1, U2, U3, U4: SN74LVC8T245PWR; PW24
U5: LCMXO2-1200HC-4TG100C; TQFP100_LAT
U6: MX29LV320EBTI-70G; TSOPI48L12X20NORMAL_MAC
U7: FM28V100-TG; TSOP-32
U8: RP2040-Zero

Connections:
+3.3V: C1.1, C3.1, C5.1, C7.1, C9.1, C10.1, C11.1, C12.1, C13.1, C14.1, C15.1, C16.1, C17.1, C18.1, C19.1, C20.1, R2.2, R3.2, R5.1, R6.1, R7.1, R8.1, R9.1, R10.1, U1.1 (VCCA), U2.1 (VCCA), U3.1 (VCCA), U4.1 (VCCA), U5.5 (VCCIO3), U5.11 (VCCIO3), U5.23 (VCCIO3), U5.26 (VCCIO2), U5.46 (VCCIO2), U5.50 (VCC), U5.55 (VCCIO1), U5.73 (VCCIO1), U5.80 (VCCIO0), U5.93 (VCCIO0), U5.100 (VCC), U6.14 (WP#/ACC), U6.37 (VCC), U7.6 (CE2), U7.8 (VDD), U8.3v3; also elsewhere on the board
+5V (USB): U8.5v
A0: U1.21 (B1)
A1: U1.20 (B2)
A2: U1.19 (B3)
A3: U1.18 (B4)
A4: U1.17 (B5)
A5: U1.16 (B6)
A6: U1.15 (B7)
A7: U1.14 (B8)
A8: U2.21 (B1)
A9: U2.20 (B2)
A10: U2.19 (B3)
A11: U2.18 (B4)
A12: U2.17 (B5)
A13: U2.16 (B6)
A14: U2.15 (B7)
A15: U2.14 (B8)
D0: U3.21 (B1)
D1: U3.20 (B2)
D2: U3.19 (B3)
D3: U3.18 (B4)
D4: U3.17 (B5)
D5: U3.16 (B6)
D6: U3.15 (B7)
D7: U3.14 (B8)
GND: C1.2, C2.2, C3.2, C4.2, C5.2, C6.2, C7.2, C8.2, C9.2, C10.2, C11.2, C12.2, C13.2, C14.2, C15.2, C16.2, C17.2, C18.2, C19.2, C20.2, R4.1, U1.2 (DIR), U1.11 (GND), U1.12 (GND), U1.13 (GND), U1.22 (*OE), U2.2 (DIR), U2.11 (GND), U2.12 (GND), U2.13 (GND), U2.22 (*OE), U3.11 (GND), U3.12 (GND), U3.13 (GND), U4.2 (DIR), U4.7 (A5), U4.8 (A6), U4.9 (A7), U4.10 (A8), U4.11 (GND), U4.12 (GND), U4.13 (GND), U4.14 (B8), U4.15 (B7), U4.16 (B6), U4.17 (B5), U4.22 (*OE), U5.6 (GND), U5.22 (GND), U5.33 (GND), U5.44 (GND), U5.56 (GND), U5.72 (GND), U5.79 (GND), U5.92 (GND), U6.27 (GND), U6.46 (GND), U6.47 (BYTE#), U7.24 (VSS), U8.GND
unnamed: R2.1, U6.12 (RESET#)
SPI_CS_N: U5.97 (PT10A), U8.1
SPI_MISO: U5.99 (PT9A), U8.0
SPI_MOSI: U5.96 (PT10B), U8.3
SPI_SCK: U5.98 (PT9B), U8.2
VCCB: C2.1, C4.1, C6.1, C8.1, U1.23 (VCCB), U1.24 (VCCB), U2.23 (VCCB), U2.24 (VCCB), U3.23 (VCCB), U3.24 (VCCB), U4.23 (VCCB), U4.24 (VCCB)
data_dir: R4.2, U3.2 (DIR), U5.57 (PR9B)
flash_a0: U5.3 (PL3A), U6.45 (Q15/A-1), U7.20 (A0)
flash_a1: U5.4 (PL3B), U6.25 (A0), U7.19 (A1)
flash_a2: U5.7 (PL3C), U6.24 (A1), U7.18 (A2)
flash_a3: U5.8 (PL3D), U6.23 (A2), U7.17 (A3)
flash_a4: U5.9 (PL4A), U6.22 (A3), U7.16 (A4)
flash_a5: U5.10 (PL4B), U6.21 (A4), U7.15 (A5)
flash_a6: U5.12 (PL5A), U6.20 (A5), U7.14 (A6)
flash_a7: U5.13 (PL5B), U6.19 (A6), U7.13 (A7)
flash_a8: U5.14 (PL5C), U6.18 (A7), U7.3 (A8)
flash_a9: U5.15 (PL5D), U6.8 (A8), U7.2 (A9)
flash_a10: U5.16 (PL8A), U6.7 (A9)
flash_a11: U5.17 (PL8B), U6.6 (A10), U7.1 (A11)
flash_a12: U5.18 (PL8C), U6.5 (A11), U7.12 (A12)
flash_a13: U5.19 (PL8D), U6.4 (A12), U7.4 (A13)
flash_a14: U5.20 (PL9A), U6.3 (A13), U7.11 (A14)
flash_a15: U5.21 (PL9B), U6.2 (A14), U7.7 (A15)
flash_a16: U5.24 (PL10C), U6.1 (A15), U7.10 (A16)
flash_a17: U5.25 (PL10D), U6.48 (A16)
flash_a18: U5.63 (PR5C), U6.17 (A17)
flash_a19: U5.64 (PR5B), U6.16 (A18)
flash_a20: U5.65 (PR5A), U6.9 (A19)
flash_a21: U5.66 (PR4D), U6.10 (A20)
flash_ce_n: R8.2, U5.77 (PT17C), U6.26 (CE#)
flash_d0: U5.67 (PR4C), U6.29 (Q0), U7.21 (DQ0)
flash_d1: U5.68 (PR4B), U6.31 (Q1), U7.22 (DQ1)
flash_d2: U5.69 (PR4A), U6.33 (Q2), U7.23 (DQ2)
flash_d3: U5.70 (PR3B), U6.35 (Q3), U7.25 (DQ3)
flash_d4: U5.71 (PR3A), U6.38 (Q4), U7.26 (DQ4)
flash_d5: U5.74 (PR2B), U6.40 (Q5), U7.27 (DQ5)
flash_d6: U5.75 (PR2A), U6.42 (Q6), U7.28 (DQ6)
flash_d7: U5.76 (PT17D), U6.44 (Q7), U7.29 (DQ7)
flash_oe_n: R9.2, U5.78 (PT16C), U6.28 (OE#)
flash_we_n: R10.2, U5.81 (PT15D), U6.11 (WE#)
fram_a10: U7.31 (A10)
fram_ce_n: R5.2, U5.82 (PT15C), U7.30 (*CE1)
fram_oe_n: R6.2, U5.83 (PT15B), U7.32 (*OE)
fram_we_n: R7.2, U5.84 (PT15A), U7.5 (*WE)
gb_a0: U1.3 (A1), U5.27 (PB4C)
gb_a1: U1.4 (A2), U5.28 (PB4D)
gb_a2: U1.5 (A3), U5.29 (PB6A)
gb_a3: U1.6 (A4), U5.30 (PB6B)
gb_a4: U1.7 (A5), U5.31 (PB6C)
gb_a5: U1.8 (A6), U5.32 (PB6D)
gb_a6: U1.9 (A7), U5.34 (PB9A)
gb_a7: U1.10 (A8), U5.35 (PB9B)
gb_a8: U2.3 (A1), U5.36 (PB11C)
gb_a9: U2.4 (A2), U5.37 (PB11D)
gb_a10: U2.5 (A3), U5.38 (PB11A)
gb_a11: U2.6 (A4), U5.39 (PB11B)
gb_a12: U2.7 (A5), U5.40 (PB15A)
gb_a13: U2.8 (A6), U5.41 (PB15B)
gb_a14: U2.9 (A7), U5.42 (PB18A)
gb_a15: U2.10 (A8), U5.43 (PB18B)
gb_cs_n: U4.5 (A3), U5.61 (PR8A)
gb_d0: U3.3 (A1), U5.45 (PB18C)
gb_d1: U3.4 (A2), U5.47 (PB18D)
gb_d2: U3.5 (A3), U5.48 (PB20C)
gb_d3: U3.6 (A4), U5.49 (PB20D)
gb_d4: U3.7 (A5), U5.51 (PR10D)
gb_d5: U3.8 (A6), U5.52 (PR10C)
gb_d6: U3.9 (A7), U5.53 (PR9D)
gb_d7: U3.10 (A8), U5.54 (PR9C)
gb_rd_n: U4.4 (A2), U5.60 (PR8C)
gb_res_n: U4.6 (A4), U5.62 (PR5D)
gb_wr_n: U4.3 (A1), U5.59 (PR8D)
/CS: U4.19 (B3)
/RD: U4.20 (B2)
/RES: U4.18 (B4)
/WR: U4.21 (B1)

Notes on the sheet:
U3: DIR=0 при записи CPU, DIR=1 при чтении; OE#=1 при смене направления
Подтяжки 10 кОм к 3,3 В: память отключена при Hi-Z FPGA

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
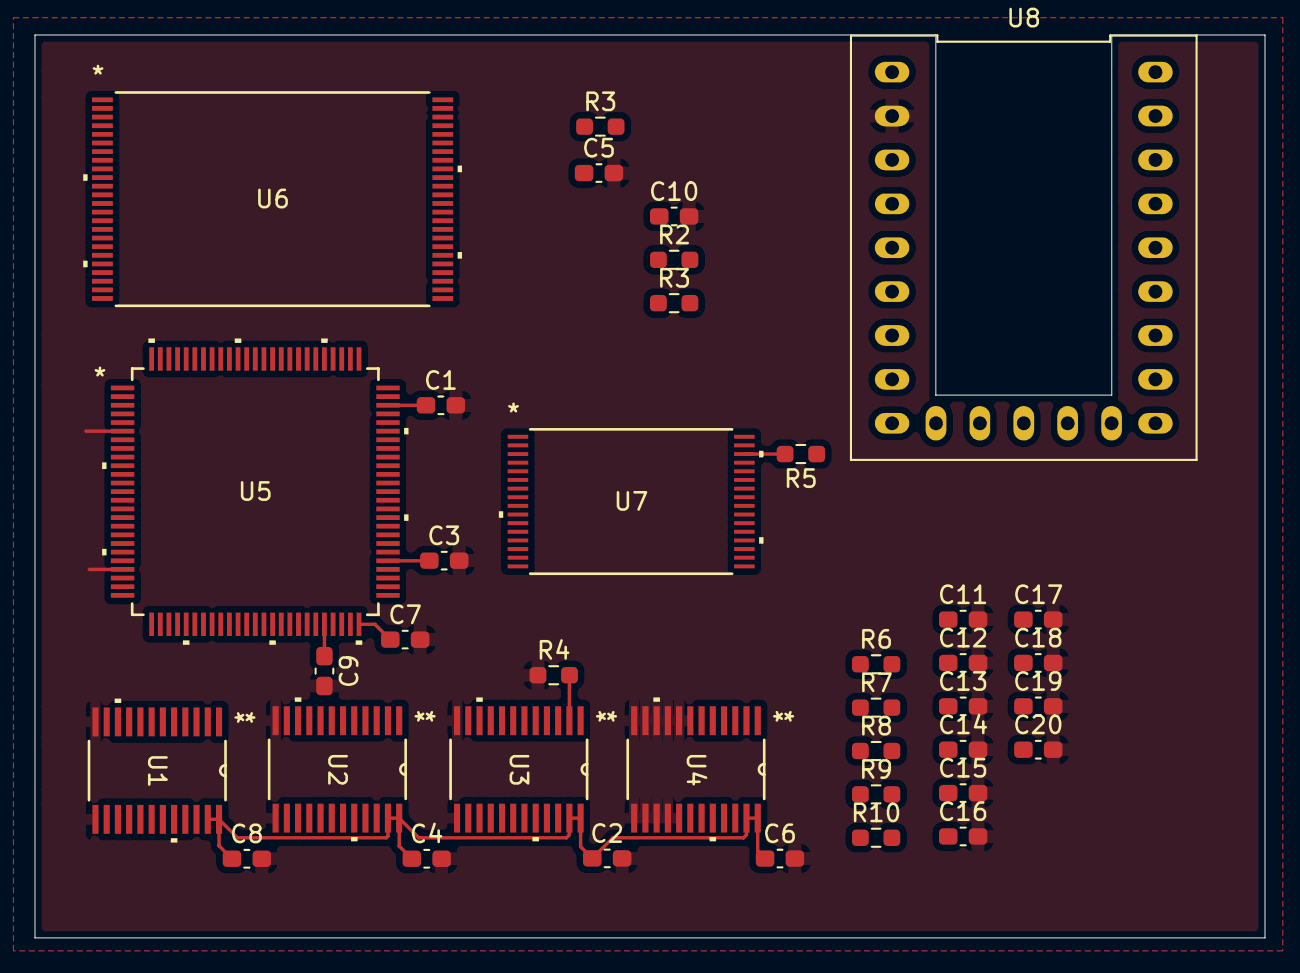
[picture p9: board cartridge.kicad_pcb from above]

Board: 2 copper layers, 71.2 x 52.2 mm, 38 parts (0 on the bottom side), 74 nets.

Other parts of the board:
R3#2: 10K; R_0603_1608Metric_Pad0.98x0.95mm_HandSolder

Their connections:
+3.3V: R3#2.2; also elsewhere on the board

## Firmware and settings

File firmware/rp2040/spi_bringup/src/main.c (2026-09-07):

#include <stdio.h>
#include <stdlib.h>
#include <string.h>

#include "pico/stdlib.h"
#include "hardware/spi.h"

#define FPGA_SPI                spi0
#define FPGA_SPI_BAUD_HZ        10000u

#define PIN_SPI_MISO            0u
#define PIN_SPI_CS_N            1u
#define PIN_SPI_SCK             2u
#define PIN_SPI_MOSI            3u

#define SPI_FRAME_GUARD_US      25u
#define GET_VERSION_CMD         0x01u
#define GET_VERSION_FRAME_LEN   9u

static const uint8_t get_version_tx[GET_VERSION_FRAME_LEN] = {
    GET_VERSION_CMD, 0x00, 0x00, 0x00, 0x00,
    0x00, 0x00, 0x00, 0x00
};

static void print_bytes(const char *label, const uint8_t *data, size_t len) {
    printf("%s", label);
    for (size_t i = 0; i < len; ++i) {
        printf("%s%02X", i == 0 ? "" : " ", data[i]);
    }
    printf("\r\n");
}

static void fpga_spi_init(void) {
    // Keep the FPGA deselected before enabling the SPI peripheral.
    gpio_init(PIN_SPI_CS_N);
    gpio_set_dir(PIN_SPI_CS_N, GPIO_OUT);
    gpio_put(PIN_SPI_CS_N, 1);

    uint actual_baud = spi_init(FPGA_SPI, FPGA_SPI_BAUD_HZ);
    spi_set_format(
        FPGA_SPI,
        8,
        SPI_CPOL_0,
        SPI_CPHA_0,
        SPI_MSB_FIRST
    );

    gpio_set_function(PIN_SPI_MISO, GPIO_FUNC_SPI);
    gpio_set_function(PIN_SPI_SCK, GPIO_FUNC_SPI);
    gpio_set_function(PIN_SPI_MOSI, GPIO_FUNC_SPI);

    // Give both ends some time to settle after configuration.
    sleep_ms(10);

    printf("SPI0 ready: requested=%u Hz actual=%u Hz, Mode 0\r\n",
           FPGA_SPI_BAUD_HZ, actual_baud);
    printf("pins: MISO=GP%u CS#=GP%u SCK=GP%u MOSI=GP%u\r\n",
           PIN_SPI_MISO, PIN_SPI_CS_N, PIN_SPI_SCK, PIN_SPI_MOSI);
}

static void fpga_spi_transfer(const uint8_t *tx, uint8_t *rx, size_t len) {
    // Protocol requires >=20 us from CS# assertion to first SCK edge.
    gpio_put(PIN_SPI_CS_N, 0);
    busy_wait_us_32(SPI_FRAME_GUARD_US);

    spi_write_read_blocking(FPGA_SPI, tx, rx, len);

    // Protocol also requires >=20 us from final SCK edge to CS# release.
    busy_wait_us_32(SPI_FRAME_GUARD_US);
    gpio_put(PIN_SPI_CS_N, 1);

    // And >=20 us between frames.
    busy_wait_us_32(SPI_FRAME_GUARD_US);
}

static bool fpga_get_version(uint8_t rx[GET_VERSION_FRAME_LEN]) {
    memset(rx, 0, GET_VERSION_FRAME_LEN);
    fpga_spi_transfer(get_version_tx, rx, GET_VERSION_FRAME_LEN);

    // rx[0] is intentionally ignored by protocol v1.0.
    return rx[1] == 'G' &&
           rx[2] == 'B' &&
           rx[3] == 'F' &&
           rx[4] == 'C' &&
           rx[5] == 1 &&
           rx[6] == 0 &&
           rx[7] == 0 &&
           rx[8] == 0;
}

static void command_version(void) {
    uint8_t rx[GET_VERSION_FRAME_LEN];
    bool ok = fpga_get_version(rx);

    print_bytes("TX: ", get_version_tx, GET_VERSION_FRAME_LEN);
    print_bytes("RX: ", rx, GET_VERSION_FRAME_LEN);

    if (ok) {
        uint8_t major = rx[5];
        uint8_t minor = rx[6];
        uint16_t capabilities = (uint16_t)rx[7] | ((uint16_t)rx[8] << 8);

        printf("OK: FPGA protocol %u.%u, capabilities=0x%04X\r\n",
               major, minor, capabilities);
    } else {
        printf("ERROR: unexpected FPGA response\r\n");
    }
}

static void command_test(unsigned long count) {
    if (count == 0) {
        printf("ERROR: count must be > 0\r\n");
        return;
    }

    unsigned long passed = 0;
    unsigned long failed = 0;
    uint8_t rx[GET_VERSION_FRAME_LEN];
    uint8_t first_bad[GET_VERSION_FRAME_LEN] = {0};
    unsigned long first_bad_index = 0;

    absolute_time_t start = get_absolute_time();

    for (unsigned long i = 0; i < count; ++i) {
        if (fpga_get_version(rx)) {
            ++passed;
        } else {
            ++failed;
            if (failed == 1) {
                memcpy(first_bad, rx, sizeof(first_bad));
                first_bad_index = i + 1;
            }
        }
    }

    int64_t elapsed_us = absolute_time_diff_us(start, get_absolute_time());

    printf("TEST: total=%lu pass=%lu fail=%lu elapsed=%lld ms\r\n",
           count, passed, failed, (long long)(elapsed_us / 1000));

    if (failed == 0) {
        printf("PASS\r\n");
    } else {
        printf("FAIL: first bad frame #%lu\r\n", first_bad_index);
        print_bytes("RX: ", first_bad, GET_VERSION_FRAME_LEN);
    }
}

static void print_help(void) {
    printf("Commands:\r\n");
    printf("  version        one GET_VERSION transaction\r\n");
    printf("  v              alias for version\r\n");
    printf("  test [N]       repeat GET_VERSION N times (default 1000)\r\n");
    printf("  help           show this help\r\n");
}

int main(void) {
    stdio_init_all();

    // This firmware is controlled through USB CDC, so wait until a host opens it.
    sleep_ms(1500);

    printf("\r\nGame Boy flash cart - RP2040 SPI bring-up\r\n");
    fpga_spi_init();
    print_help();

    char line[64];

    while (true) {
        printf("> ");
        fflush(stdout);

        if (fgets(line, sizeof(line), stdin) == NULL) {
            clearerr(stdin);
            sleep_ms(10);
            continue;
        }

        line[strcspn(line, "\r\n")] = '\0';

        if (strcmp(line, "version") == 0 || strcmp(line, "v") == 0) {
            command_version();
            continue;
        }

        if (strncmp(line, "test", 4) == 0 &&
            (line[4] == '\0' || line[4] == ' ' || line[4] == '\t')) {
            char *arg = line + 4;
            while (*arg == ' ' || *arg == '\t') {
                ++arg;
            }

            unsigned long count = 1000;
            if (*arg != '\0') {
                char *end = NULL;
                unsigned long parsed = strtoul(arg, &end, 10);
                if (end == arg || *end != '\0') {
                    printf("ERROR: usage: test [N]\r\n");
                    continue;
                }
                count = parsed;
            }

            command_test(count);
            continue;
        }

        if (strcmp(line, "help") == 0 || strcmp(line, "?") == 0) {
            print_help();
            continue;
        }

        if (line[0] != '\0') {
            printf("ERROR: unknown command '%s'\r\n", line);
            print_help();
        }
    }
}

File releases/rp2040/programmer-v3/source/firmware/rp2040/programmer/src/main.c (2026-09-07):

// Binary USB bridge for FPGA programmer protocol 3. See docs/PROGRAMMER_PROTOCOL.md.
#include <stdio.h>
#include <stdint.h>
#include <string.h>
#include "pico/stdlib.h"
#include "hardware/spi.h"
#define BLOCK 1024
#define MAX_REQUEST (BLOCK + 10)
#define MAX_REPLY (BLOCK + 12)
#ifndef GB_SPI_HZ
#define GB_SPI_HZ 4000000
#endif
static uint8_t request[MAX_REQUEST], response[MAX_REPLY];
static uint16_t crc16(const uint8_t *p, size_t n) {
    uint16_t c=0xffff;
    while(n--) {
        c^=(uint16_t)*p++<<8;
        for(int i=0;i<8;++i) c=(uint16_t)((c<<1)^((c&0x8000)?0x1021:0));
    }
    return c;
}
static bool valid(const uint8_t *p, size_t n) {
    return n>=2 && crc16(p,n-2)==((uint16_t)p[n-2]<<8|p[n-1]);
}
static void select_spi(void) { gpio_put(1,0); busy_wait_us_32(2); }
static void release_spi(void) { busy_wait_us_32(2); gpio_put(1,1); busy_wait_us_32(2); }
static void query(uint8_t op, uint8_t *out, size_t n) {
    select_spi(); spi_write_blocking(spi0,&op,1);
    spi_read_blocking(spi0,0,out,n); release_spi();
}
static bool get_status(uint8_t *out) {
    query(2,out,10); return out[0]==0x50 && valid(out,10);
}
static size_t execute(size_t n) {
    if(n==1 && request[0]==1) { query(1,response,8); return 8; }
    if(n==1 && request[0]==2) {
        if(get_status(response)) return 10;
        response[0]=0xe1; return 1;
    }
    if(n<10 || !valid(request,n)) { response[0]=0xe2; return 1; }
    const uint8_t op=request[0], seq=request[1];
    const size_t length=(size_t)request[5]<<8|request[6];
    if((op==0x30 || op==0x31) ? (length==0 || length>BLOCK) : length!=0) {
        response[0]=0xe2; return 1;
    }
    if(n!=10+(op==0x31?length:0) ||
       !(op==0x30 || op==0x31 || op==0x12 || op==0x13 || op==0x14 || op==0x20 || op==0x21)) {
        response[0]=0xe2; return 1;
    }
    if(!get_status(response) || response[2]==1 || response[1]==seq) {
        response[0]=0xe3; return 1;
    }
    select_spi(); spi_write_blocking(spi0,request,n); release_spi();
    // A worst-case 1024-byte block can take >2 s (per-byte timeout).
    absolute_time_t deadline=make_timeout_time_ms(7000);
    do {
        if(!get_status(response)) { response[0]=0xe1; return 1; }
        if(response[1]==seq && response[3]==op && response[2]!=1) {
            if(response[2]==0 && op==0x30) {
                if(((size_t)response[6]|(size_t)response[7]<<8)!=length) {
                    response[0]=0xe3; return 1;
                }
                query(3,response+10,length+2);
                if(!valid(response+10,length+2)) { response[0]=0xe1; return 1; }
                return 10+length+2;
            }
            return 10;
        }
        busy_wait_us_32(20);
    } while(!time_reached(deadline));
    response[0]=0xe4; return 1; // Never retry a possibly committed operation.
}
static bool receive(uint8_t *p, size_t n, absolute_time_t deadline) {
    while(n) {
        int c=getchar_timeout_us(1000);
        if(c!=PICO_ERROR_TIMEOUT) { *p++=(uint8_t)c; --n; }
        else if(time_reached(deadline)) return false;
    }
    return true;
}
static void send_reply(size_t n) {
    static uint8_t frame[MAX_REPLY+8];
    memcpy(frame,"GB3R",4); frame[4]=(uint8_t)(n>>8); frame[5]=(uint8_t)n;
    memcpy(frame+6,response,n);
    uint16_t crc=crc16(frame+4,n+2);
    frame[n+6]=(uint8_t)(crc>>8); frame[n+7]=(uint8_t)crc;
    stdio_put_string((const char *)frame,(int)(n+8),false,false);
    stdio_flush();
}
int main(void) {
    stdio_init_all();
    gpio_init(1); gpio_put(1,1); gpio_set_dir(1,GPIO_OUT);
    spi_init(spi0,GB_SPI_HZ);
    spi_set_format(spi0,8,SPI_CPOL_0,SPI_CPHA_0,SPI_MSB_FIRST);
    gpio_set_function(0,GPIO_FUNC_SPI); gpio_set_function(2,GPIO_FUNC_SPI);
    gpio_set_function(3,GPIO_FUNC_SPI);
    sleep_ms(400);
    static uint8_t frame[MAX_REQUEST+4];
    unsigned matched=0;
    bool discard=false;
    while(true) {
        int c=getchar_timeout_us(100000);
        if(c==PICO_ERROR_TIMEOUT) { matched=0; discard=false; continue; }
        // After damaged framing, drain until a 100 ms idle gap; do not scan
        // the remaining binary payload for accidental embedded commands.
        if(discard) continue;
        if((uint8_t)c!=(uint8_t)"GB3Q"[matched]) { matched=0; discard=true; continue; }
        if(++matched<4) continue;
        matched=0;
        absolute_time_t deadline=make_timeout_time_ms(2000);
        if(!receive(frame,2,deadline)) { discard=true; continue; }
        size_t n=(size_t)frame[0]<<8|frame[1];
        if(n==0 || n>MAX_REQUEST || !receive(frame+2,n+2,deadline) || !valid(frame,n+4)) {
            response[0]=0xe2; send_reply(1); discard=true; continue;
        }
        memcpy(request,frame+2,n); send_reply(execute(n));
    }
}

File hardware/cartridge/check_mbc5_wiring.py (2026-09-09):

#!/usr/bin/env python3
"""Сверка экспортированной KiCad XML-сетки с назначениями MBC5."""
from pathlib import Path
import re
import sys
import xml.etree.ElementTree as ET

root = Path(__file__).resolve().parents[2]
nets = ET.parse(sys.argv[1]).getroot().findall('./nets/net')
by_pin = {}
for net in nets:
    for node in net.findall('node'):
        key = (node.get('ref'), int(node.get('pin'))) if node.get('ref') != 'U8' else None
        if key:
            by_pin[key] = net.get('name').lstrip('/')

def check(ref, pin, name):
    actual = by_pin.get((ref, pin))
    assert actual == name, f'{ref}.{pin}: {actual!r} != {name!r}'

lpf = (root / 'fpga/constraints/game_mbc5.lpf').read_text()
ports = re.findall(r'LOCATE COMP "([^"]+)" SITE "(\d+)"', lpf)
assert len(ports) == len({name for name, _ in ports}) == len({pin for _, pin in ports}) == 66
for name, pin in ports:
    check('U5', int(pin), name.replace('[', '').replace(']', ''))
    assert f'IOBUF PORT "{name}" IO_TYPE=LVCMOS33' in lpf

addr_pins = [20, 19, 18, 17, 16, 15, 14, 13, 3, 2, 31, 1, 12, 4, 11, 7, 10]
data_pins = [21, 22, 23, 25, 26, 27, 28, 29]
flash_addr_pins = [45, 25, 24, 23, 22, 21, 20, 19, 18, 8, 7, 6, 5, 4, 3, 2, 1]
flash_data_pins = [29, 31, 33, 35, 38, 40, 42, 44]
for i, pin in enumerate(addr_pins):
    check('U7', pin, f'flash_a{i}')
    check('U6', flash_addr_pins[i], f'flash_a{i}')
for i, pin in enumerate(data_pins):
    check('U7', pin, f'flash_d{i}')
    check('U6', flash_data_pins[i], f'flash_d{i}')
for pin, name in [(30, 'fram_ce_n'), (32, 'fram_oe_n'), (5, 'fram_we_n'),
                  (6, '+3.3V'), (8, '+3.3V'), (24, 'GND')]:
    check('U7', pin, name)
assert by_pin['U7', 9].startswith('unconnected-')
for i, name in enumerate(['fram_ce_n', 'fram_oe_n', 'fram_we_n',
                          'flash_ce_n', 'flash_oe_n', 'flash_we_n'], 5):
    assert {by_pin[f'R{i}', 1], by_pin[f'R{i}', 2]} == {name, '+3.3V'}
for ref, offset in [('U1', 0), ('U2', 8)]:
    for i in range(8):
        check(ref, i + 3, f'gb_a{i + offset}')
for pin, name in [(2, 'GND'), (22, 'GND'), (3, 'gb_wr_n'), (4, 'gb_rd_n'),
                  (5, 'gb_cs_n'), (6, 'gb_res_n')]:
    check('U4', pin, name)
check('U3', 2, 'data_dir')
check('U3', 22, 'data_oe_n')
check('C10', 1, '+3.3V')
check('C10', 2, 'GND')
print('PASS: 66 назначений FPGA, все выводы F-RAM, общие шины, U1/U2/U3/U4 и подтяжки')

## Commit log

2026-09-03 Store gerbers in git
2026-09-03 Add cartridge schematics with proper footprints
    [cartridge.kicad_pcb, cartridge.kicad_sch]
2026-09-03 Fix ROM memory connections
    [cartridge.kicad_sch]
2026-09-03 Add PCB
    [cartridge.kicad_pcb, cartridge.kicad_sch]
2026-09-04 Add ROM_test.v, cleanup
    [lsdj_cart_signal_pin_assignment_revA.xlsx, lsdj_cart_signal_pin_assignment_revA_shared_bus.xlsx]
2026-09-04 Марафет
    [misc components.csv, misc-components-legacy.csv]
2026-09-05 Add RP2040, caps, 3D models
    [FM28V100-TG.stp, LCMXO2-1200HC-4TG100C.stp, MX29LV320EBTI-70G.stp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]
2026-09-06 Test failed, update test plan, status, roadmap
    [FPGA-SC-02009-1-44-MachXO2-1200-Pinout.csv]
2026-09-06 Fix Flash test, now actually working!
    [flash_bringup_tb.sv, top.v]
2026-09-06 Add spi_bringup (draft)
    [cartridge.kicad_sch]
2026-09-07 Add RP2040 SPI firmware (untested)
    [cartridge.kicad_pcb]
2026-09-07 Fix RP2040 firmware build, add release
    [main.c]
2026-09-07 Passed SPI bring-up test
2026-09-07 Timing fix attempt 1
    [programmer_block.v]
2026-09-08 Update schematics
    [cartridge.kicad_pcb, cartridge.kicad_sch]
2026-09-08 Update plan and schematics
    [cartridge.kicad_pcb, cartridge.kicad_sch]
2026-09-09 add game_mbc5 target
    [cartridge.kicad_sch]
